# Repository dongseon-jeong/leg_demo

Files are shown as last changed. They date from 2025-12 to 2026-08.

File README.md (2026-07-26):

# 준비

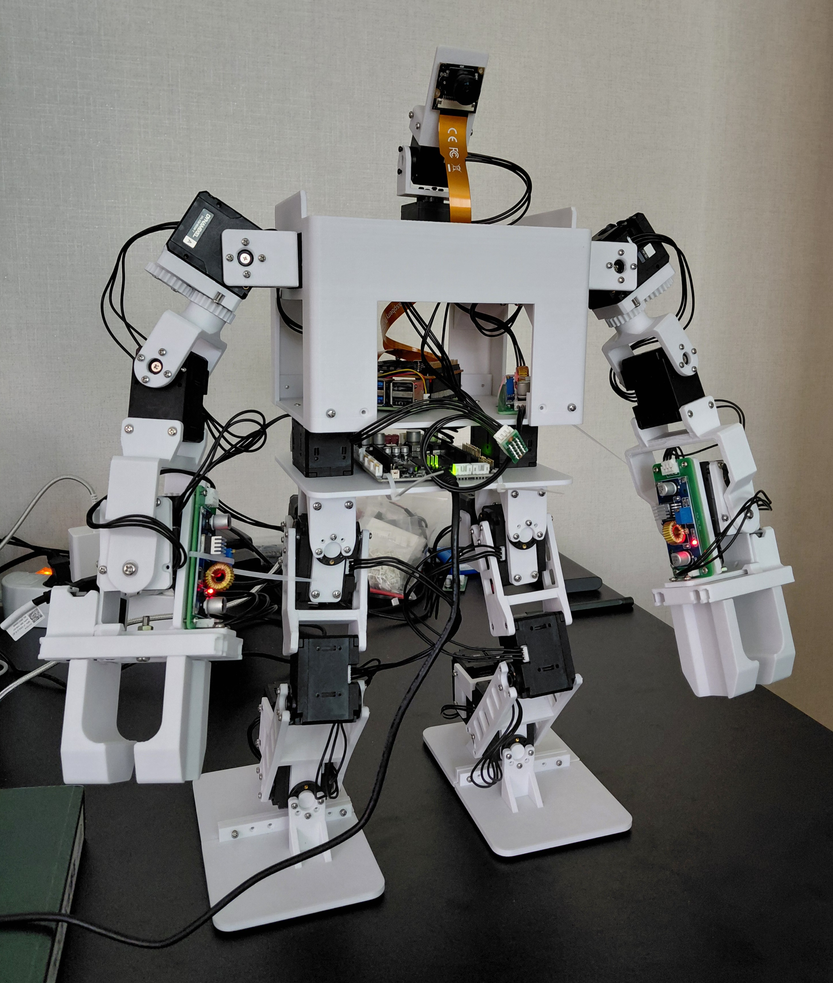
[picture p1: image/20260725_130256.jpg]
이미지

이미지

- 로봇
	- op3 leg + toddlerbot arm + rgb camera
- 최종로봇목표
	- 하체는 밸런싱 보드에서 균형 잡고 상체는 책상 위 주사위를 들어 번호 순으로 여러 개를 쌓는 작업을 구현 목표
- 학습
	- 하체는 isaaclab 강화학습
	- 상체는 lerobot 모방학습
	- +상하체 보강용 강화학습
- 추론
	- 상하체 모델 출력 + 보강용 모델 결과
- 부품
	- 하체 다이나믹셀 XL430-W350-R x 12
	- 상체 다이나믹셀 XL430 x 4 , 2XL430 x 4 , XL330 x 4
	- rgb 카메라
	- opencr, u2d2, rasberrypi5, ai hat+, buck converter, dynamixel hub
	- oculus quest2
	- 리튬베터리 11v
	- 나사 2 x 8, 2.5 x 8 많이 
	- 황동 히트 인서트 2 x 2, 2.5 x 2 많이
- system
  - edge inference : rasberrypi5(opencr) hailo8G debian venv ros noetic
  - simulation : rtx3080 desktop window11/ubuntu24.04 cuda12.8 isaacsim ros2 humble
  - train : ascent gx10 128G ubuntu cuda13
    - lerobot venv
    - isaaclab conda
  - teleop : rtx3080 desktop ubuntu24.04

이미지

# 4. 멀티 태스크 구현

# 5. 협동 로봇 구현

# 참고
https://github.com/ROBOTIS-GIT/ROBOTIS-OP3-Common  
https://www.robotis.com/service/downloadpage.php?ca_id=70  
https://emanual.robotis.com/docs/en/platform/op3/robotis_ros_packages/#robotis-ros-packages  
https://www.youtube.com/watch?v=tQziqSx-F80&t=1970s  
https://github.com/kscalelabs/ksim-gym/tree/master  
https://github.com/hshi74/toddlerbot

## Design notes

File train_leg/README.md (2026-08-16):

## 3d 프린팅 부품 설계

- 3d 프로그램
  - onshape : sas 서비스이고, isaacsim에서 바로 onshape로봇을 불러올 수 있음
  - fusion : autodesk cad나 maya 등이 익숙하다면 사용, claude 모델을 mcp로 연결해도 됨, 개인용도는 무료
- op3의 stl 파일이 있으나 본래 부분은 금속소재로 플라스틱 출력 시의 강도가 예상되지 않아, 새로 적당한 두께로 설계
- 모터 stl를 불러와서 사용하고 다른 부분의 스케치가 없어서 대략적으로 스케치하여 모델링 

[다이나믹셀 step파일](https://www.robotis.com/service/downloadpage.php?ca_id=70)  
나사, 각종 보드는 구글에서 모델링 파일 검색하면 쉽게 구할 수 있음

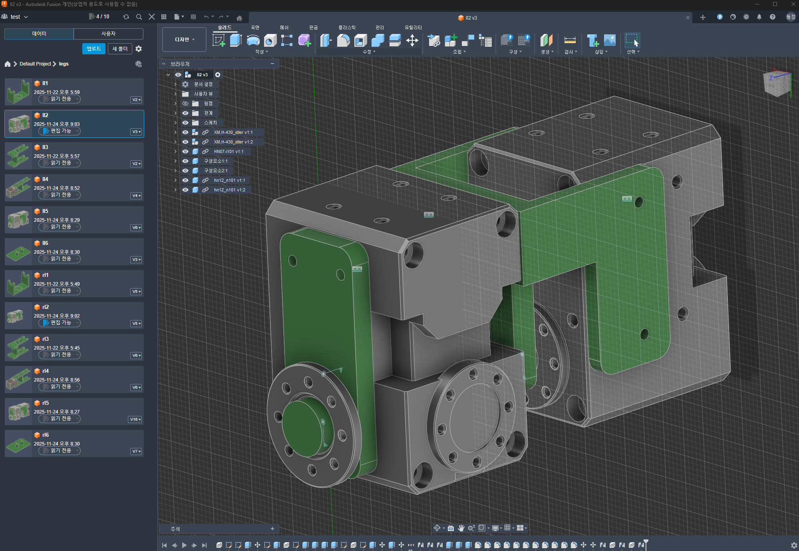
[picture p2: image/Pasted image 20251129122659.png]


## 3d 조립 완성 및 단순구조 변환

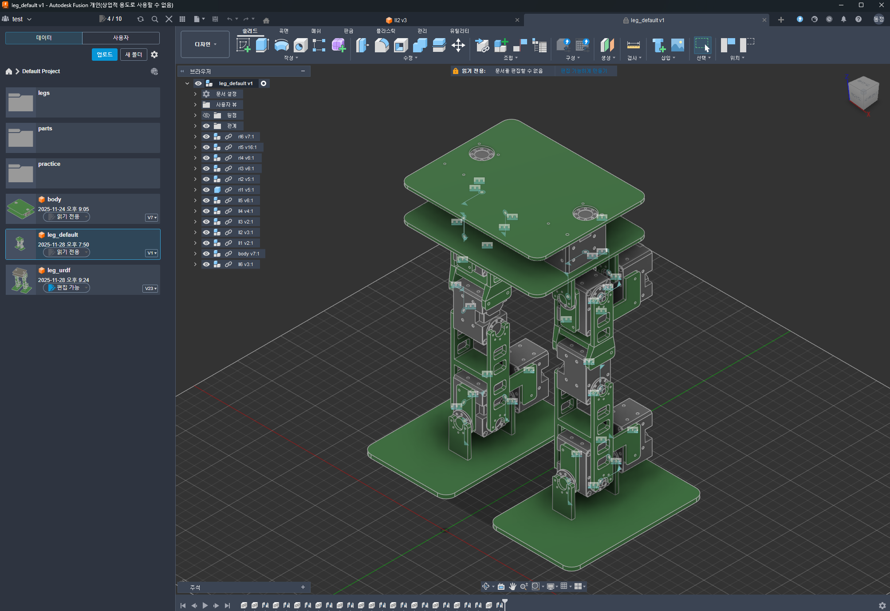
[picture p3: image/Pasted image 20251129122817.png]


- 하단 git 레포 참고하여 fusion 애드인 설치 진행
- 단순 구조로 변환
    - 모든 부위를 하나의 본체로만 구성
    - 모터 조인트 설정 시 부모 자식의 순서를 잘 맞춤, 조인트 한계각도 설정
	- 모터의 회전 조인트 및 구성요소 이름 설정  
	- fusion2urdf repo에 유의사항을 체크하여 아래와 같이 변환해야 urdf 변환 오류가 발생안됨

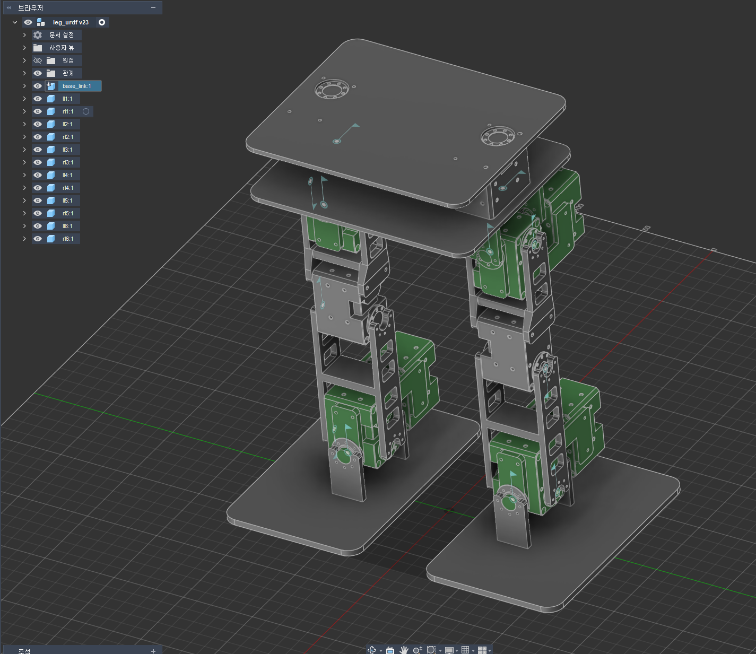
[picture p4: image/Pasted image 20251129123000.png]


https://github.com/dheena2k2/fusion2urdf-ros2
https://github.com/runtimerobotics/fusion360-urdf-ros2

## urdf 변환 및 usd 파일 생성

- urdf 추출 후 기본 세팅 진행  
추출경로 urdf폴더에 4개의 파일이 생성됨
*.gazebo *.trans *.xacro materials.xacro
xacro파일은 isaacsim에서 불어올 수 없어 urdf 변환이 필요함

- xacro > urdf 변환
  - ros2로 변환 가능
  - *.xacro의 확장자를 urdf로 바꾸고 내부에서 import하는 부분을 지운 뒤 .trans와 materials.xacro 파일 내부 내용을 urdf에 복사해도 됨
- 각종 오류 체크
  - inertia mass가 0이거나 damping 값이 없으면 isaacsim에서 오류 발생할 수 있어서 urdf에서 수정하거나 로드 후 값 입력
  - 각 joint drive의 stiffness는 isaacsim에서 입력

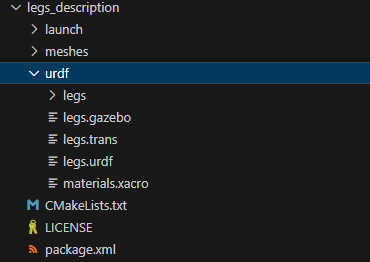
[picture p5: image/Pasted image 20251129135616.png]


- isaacsim & isaaclab 설치  
  - 환경 구성  
    - window 11 / rtx 3080 8G / 566.36 nvidia driver / cuda toolkit 12.8
    - anaconda 환경 python 3.11

        isaaclab 2.3.0  
        isaacsim 5.1.0  
        torch 2.7.0+cu128  
        torchvision 0.22.0+cu128  

- isaacsim 실행하여 urdf 파일 import하여
  - inertial collision friction damping stiffness 등 설정하여 usd 저장  
  - legs를 default prim 설정  
  - collider 등 기본 설정이 잘못되면 학습도 안됨  
  - root joint는 제거, 고정 암일 경우나 필요  

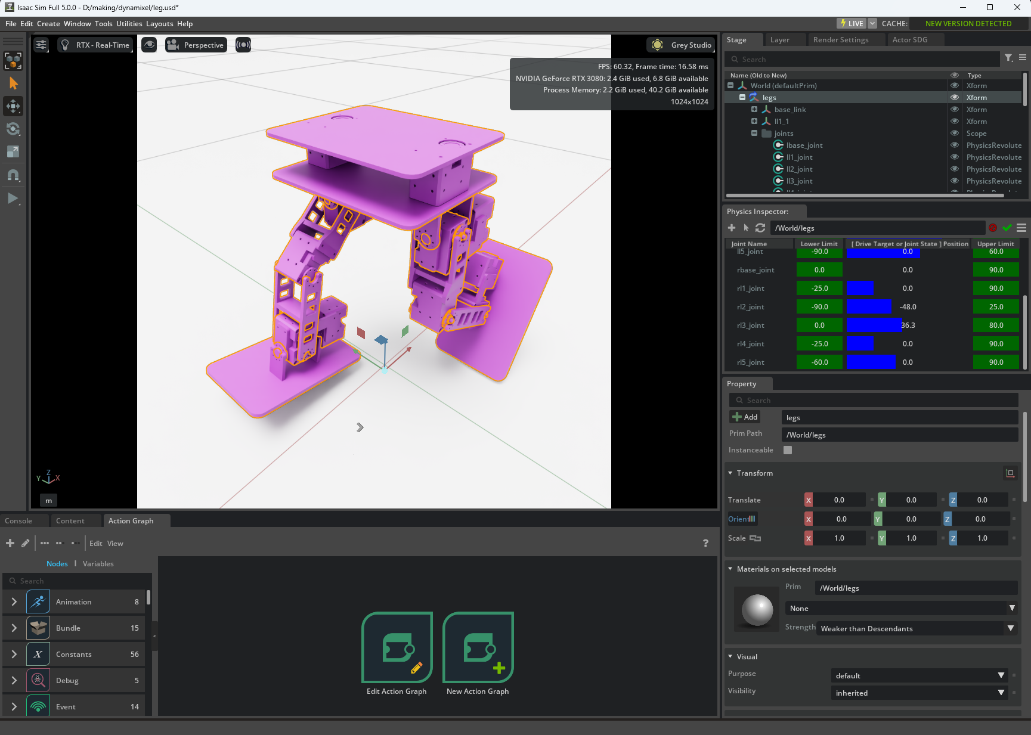
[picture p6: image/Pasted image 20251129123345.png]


## isaaclab 걷기 학습

환경 생성
```bash
./isaaclab.sh --new
Task type : Externel
Project path : d:/making/dynamixel/leg
Project name : leg
Direct | single-agent
rsl_rel, skrl
AMP, PPO
```

- 기본으로 생성하면 다음과 같이 생성됨
- cart pole로 되어 있어 커스텀 코드로 수정

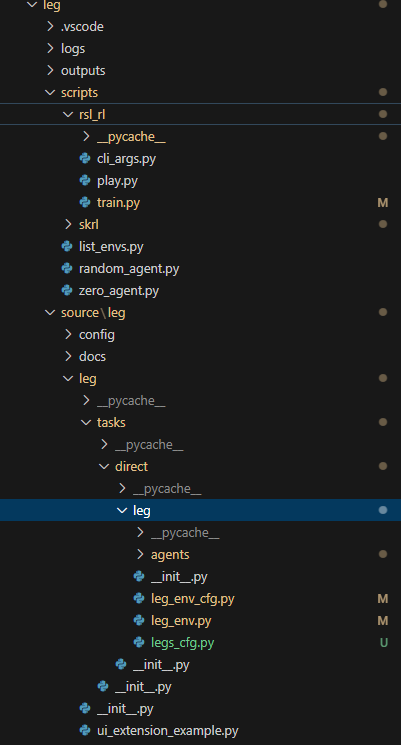
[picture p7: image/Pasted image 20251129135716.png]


- usd 파일  
leg\source\leg\leg\tasks\direct\leg\legs_cfg.py
```d
stiffness={".*": 5000.0}, # 너무 낮으면 몸의 무게감이 없음, 500이상 추천 
damping={".*": 10.0}, # 
velocity_limit_sim={".*": 10.0},
```

- 기본 환경 설정  
leg\source\leg\leg\tasks\direct\leg\leg_env_cfg.py

- 액션 스페이스 및 보상 등 중요한 환경 요소 수정  
leg\source\leg\leg\tasks\direct\leg\leg_env.py

**기본보상**  
해당 보상만으로 진행 시 한다리로 지탱하며 앞으로 콩콩 뛰어감  
```d
rew_alive # 안넘어지고 살아있으면 보상
rew_termination # 넘어지면 패널티
rew_upright # 바디의 높이가 유지되면 보상
rew_forward # 월드 x방향(로봇의 초기 앞쪽)으로 진행 시 보상, 너무 높으면 걷지 못하고 넘어짐
rew_vel_track # 원하는 속도에 도달하면 보상
rew_heading # 몸의 방향과 월드 x방향이 동일할 경우 보상, 없다면 진행 시 시계방향으로 돌아감
```
**추가보상1**  
걷기 모션을 위해 추가, 월드 x방향 직선 보행이 아닌 y방향이 포함된 대각선 보행이 발생
```d
rew_foot_spacing # 다리 간격, 없어도 무관할 듯
rew_foot_height # 발 높이, 발 교대 보상
rew_foot_flat # 발 평면 유지, 지면이 평평하다는 조건 하
```
**추가보상2**  
```d
rew_yaw_rate # 몸이 돌아가는 걸 방지, 게걸음으로 진행하는 걸 방지
rew_lateral_world # y방향 패널티, 게걸음으로 진행하는 걸 방지
```

- 모델 관련  
leg\source\leg\leg\tasks\direct\leg\agents\rsl_rl_ppo_cfg.py  

학습 초기 보상만을 얻기위한 요령을 터득하는 걸 방지하기 위해 탐색을 좀 더 하도록 수정
```d
    policy = RslRlPpoActorCriticCfg(
        init_noise_std=2.0, # 초기탐색
        actor_obs_normalization=False,
        critic_obs_normalization=False,
        actor_hidden_dims=[32, 32],
        critic_hidden_dims=[32, 32],
        activation="elu",
    )
    algorithm = RslRlPpoAlgorithmCfg(
        value_loss_coef=0.5, #
        use_clipped_value_loss=True,
        clip_param=0.2,
        entropy_coef=0.001, # 탐색 더하게
        num_learning_epochs=5,
        num_mini_batches=4,
        learning_rate=2.5e-4, #
        schedule="adaptive",
        gamma=0.99,
        lam=0.95,
        desired_kl=0.01,
        max_grad_norm=1.0,
    )
```

- 그 외 확인할 것  
leg\scripts\rsl_rl\train.py

- 학습 실행  
3080 pc 약 1시간 소요
```bash
# 환경 변수 추가
export BASE_PATH="복사한경로"

python scripts/rsl_rl/train.py --task=Template-Leg-Direct-v0 --num_envs=200 --max_iterations=5000
```

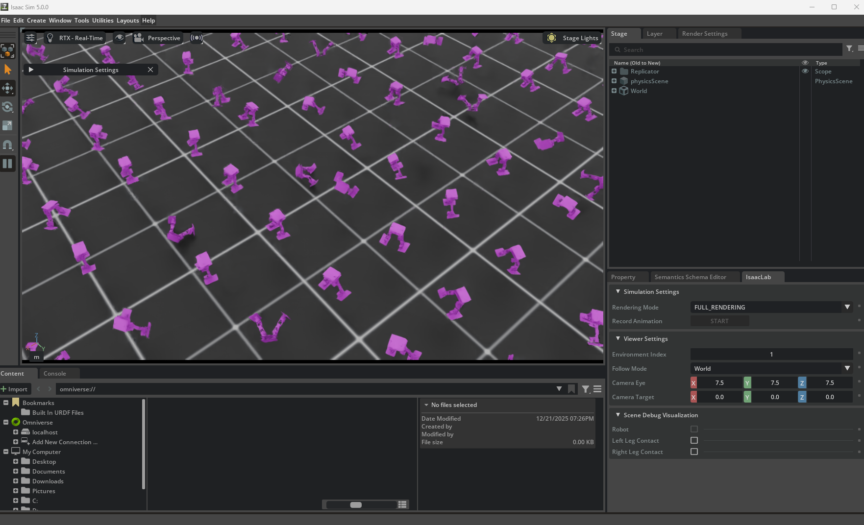
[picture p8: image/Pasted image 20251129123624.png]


모든 그래프가 우상향으로 그려지는지 모니터링
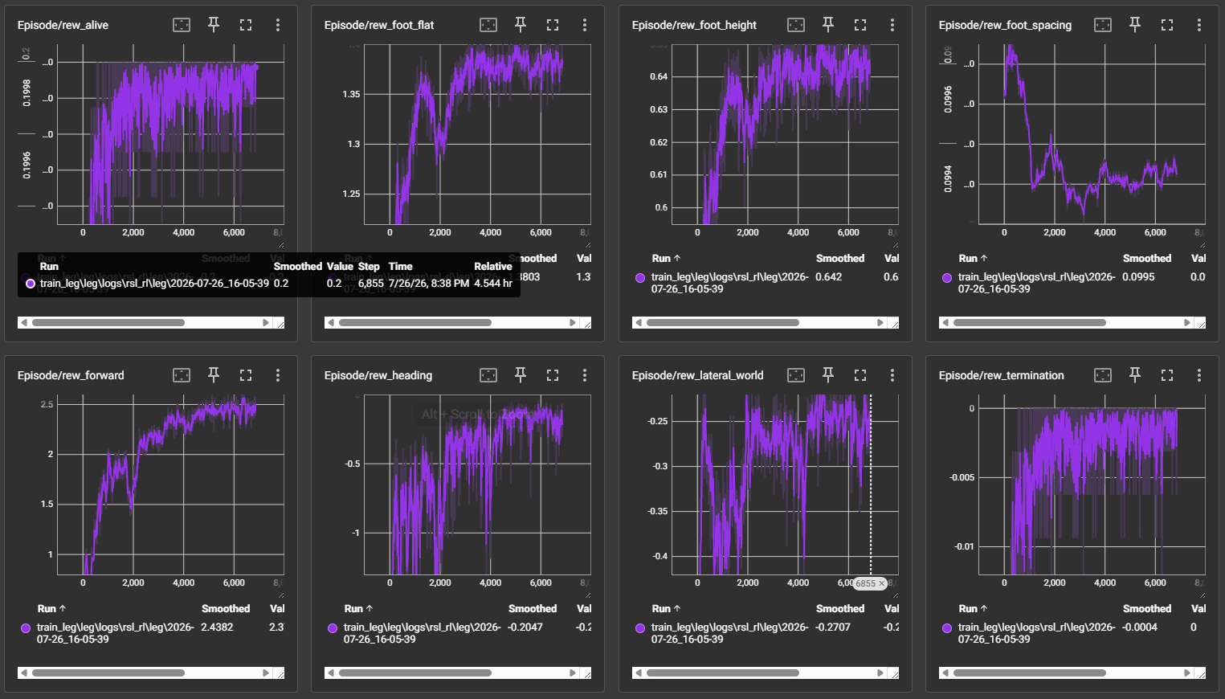
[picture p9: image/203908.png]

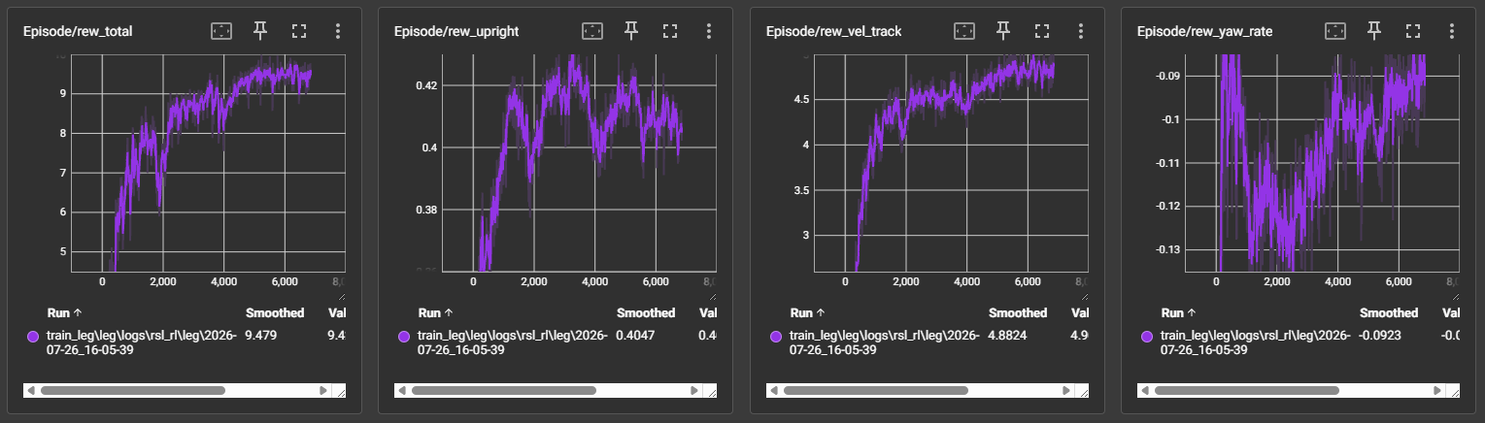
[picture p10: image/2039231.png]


```d
################################################################################
                     Learning iteration 6006/10000

                       Computation: 782 steps/s (collection: 1.874s, learning 0.171s)
             Mean action noise std: 1.59
          Mean value_function loss: 235.4259
               Mean surrogate loss: -0.0118
                 Mean entropy loss: 22.2170
                       Mean reward: 2657.49
               Mean episode length: 274.92
            Mean episode rew_alive: 0.2000
      Mean episode rew_termination: 0.0000
          Mean episode rew_upright: 0.4077
          Mean episode rew_forward: 2.5196
        Mean episode rew_vel_track: 4.9062
          Mean episode rew_heading: -0.1460
         Mean episode rew_yaw_rate: -0.0861
    Mean episode rew_lateral_world: -0.2155
     Mean episode rew_foot_spacing: 0.0995
      Mean episode rew_foot_height: 0.6573
        Mean episode rew_foot_flat: 1.4078
            Mean episode rew_total: 9.7506
--------------------------------------------------------------------------------
                   Total timesteps: 9611200
                    Iteration time: 2.04s
                      Time elapsed: 03:58:10
                               ETA: 02:38:21
```

- 추론
```bash
$env:BASE_PATH="{$project_path}/train_leg"
cd {$project_path}/train_leg/leg
python scripts/rsl_rl/play.py --task Template-Leg-Direct-v0 --num_envs 20 --checkpoint ./model_4999.pt
```

https://github.com/user-attachments/assets/a8d00207-1886-4957-bb30-7761e3211d93

## 3d 프린팅 조립
- 각 stl 파일 프린팅 > 구조 강도 개선과 조립 위해 특정 부품은 새롭게 모델링 진행  
프린팅 시 나사 구멍 등이 수축됨, 히트 인서트를 모든 나사 구멍에 삽입하는 것은 매우 힘든 일이므로 테스트 출력으로 나사 구멍 사이즈 조정 필요
- 각 부품 무게 측정 > 실제 무게로 usd 파일 설정

이미지

## 아두이노 opencr 모터컨트롤

**다이나밀셀 위저드로도 기본 설정 가능  
- 아두이노 ide에 opencr 설치 후 usb 연결하면 보드확인 및 라이브러리 사용 가능함  
- 처음 연결하면 공장 초기화 모터아이디는 모두 1번임, 모터 체인에 따라 차례대로 번호 세팅을 해야함  
  
여기에서는 왼발 위쪽 부터 차례대로 1~6번  
오른발 위쪽 부터 차례대로 7~12번 세팅  

```arduino
check_motor_id.io 보드를 usb 연결 후 코드 실행 하면 시리얼 모니터로 모터 아이디 번호 확인 가능
edit_motor_id.io 실행 하면 모터 아이디를 수정 가능
check_motor_position.io 현 모터의 포지션 수치를 시리얼 모니터로 확인
```

**중요
urdf에 저장된 조인트 라디안 min max값을 적용하면 실제 모터 방향과 다르게 움직여 다음과 같이 적용함 (fusion에서 접합 구동으로 로봇을 조정 후 urdf 파일로 변환한 이유일 것으로 추측)  

```arduino
const float URDF_MIN_RAD[12] = {
  -1.57,   -1.57,   -1.57,    0.0,   -0.43, -1.04, // 왼발 (1번: -1.57)
  0.0,     -0.43,   -0.43,   -1.39,  -1.57, -1.57  // 오른발 (7번: 0.0)
};

const float URDF_MAX_RAD[12] = {
  0.0,    0.43,     0.43,     1.39,   1.57,  1.57,  // 왼발 (1번: 0.0)
  1.57,   1.57,     1.57,     0.0,    0.43,  1.04   // 오른발 (7번: 1.57)
};
```

다음값을 각 모터에 입력하면 라디안 변환하여 움직여짐(180도에 해당하는 모터 값은 2048임, 1000은 약 90도)  
```arduino
1: -1000 ~ 0
2: -1000 ~ +200
3: +1000 ~ -200
4: -1000 ~ 0
5: -1000 ~ +200
6: -1000 ~ +300

7: 0 ~ +1000
8: -200 ~ +1000
9: -1000 ~ +200
10: 0 ~ +1000
11: -200 ~ +1000
12: -300 ~ +1000
```

```arduino
motor_control.io opencr 구동 시 위치를 초기값으로 설정하게끔 되어 있음, 라즈베리파이에서 값을 python 스크립트나 ros로 통신하기 위한 코드, usb 연결하여 실행 후 업로드 완료하면 라즈베리파이에 usb연결하여 사용
```

## rasberrypi opencr 연결
- opencr과 rasberrypi는 usb로 연결
- rasberrypi 환경설정
  - 데비안 설치
  - venv Python 3.13.5
  - ros noetic container
    - ros:noetic-ros-base-focal  
- 라즈베리파이 파이썬 스크립트 컨트롤  
venv에서 rpi_joint_teleop.py 실행 후 원하는 모터와 라디안(90도 = 1024) 입력

- ros 컨트롤 (rbiz에서 슬라이더로 모터를 컨트롤)
라즈베리파이는 ros noetic 컨테이너 실행

```bash
# 초기 세팅 외부 호스트
# 1. 모든 로컬 사용자의 디스플레이 접근 제한을 완전히 해제 (보안 비활성화) 
xhost + 
# 2. Xauthority 인증 파일 권한을 모두가 읽을 수 있도록 개방 
chmod 644 ~/.Xauthority

# 초기 세팅 컨테이너 내부
apt update
apt install -y ros-noetic-joint-state-publisher-gui ros-noetic-robot-state-publisher ros-noetic-rviz
apt install -y python-is-python3
apt install -y python3-pip 
pip3 install pyserial

# 컨테이너 외부 호스트
# 1. 디스플레이 :0 환경변수를 임시 지정하여 xhost 무력화
DISPLAY=:0 xhost +local:docker

# 2. 만약 위 명령어가 실패하면 디바이스 전체 개방으로 재시도
DISPLAY=:0 xhost +

# 컨테이너 내부
source /opt/ros/noetic/setup.bash

cd /workspace/catkin_ws 
# catkin_make 
source devel/setup.bash # 런치 파일 실행 

# 1. 완벽한 소프트웨어 렌더링 강제 (Mesa softpipe 지정) 
export LIBGL_ALWAYS_SOFTWARE=1 
export GALLIUM_DRIVER=softpipe 
# 2. X11 공유 메모리 버퍼 완전히 비활성화 (Segmentation Fault 차단 핵심) 
export QT_X11_NO_MITSHM=1 
export MITSHM=0 
# 3. 만약 하이딩된 세션 에러 방지를 위해 디스플레이 다시 선언 
export DISPLAY=:0
roslaunch opencr_rcm_control display_and_control.launch
```

## isaacsim sim2real 구현

conda에 isaacsim은 ros2라서 ros1과 통신할 브릿지 역할의 웹소켓을 같이 띄움  
isaacsim에서 조인트 damping stiffness 설정 필요

```
[호스트 isaac_bin conda]
  Isaac Sim 5.0
  → ROS2 /joint_states 퍼블리시
  → roslibpy 클라이언트
        ↕ WebSocket (LAN)
[라즈베리파이 Docker: ros_noetic]
  rosbridge_server (WebSocket :9090)
  → roscore
  → 로봇 (/dev/ttyACM0)
```

ros1 rasberrypi 컨테이너
```bash
apt update 
apt install -y ros-noetic-rosbridge-suite 
source /opt/ros/noetic/setup.bash 
roslaunch rosbridge_server rosbridge_websocket.launch
```

conda
```bash
pip install roslibpy

isaacsim --enable isaacsim.ros2.bridge --enable isaacsim.ros2.sim_control --enable omni.isaac.ros2_bridge
```

leg_w.usd 파일 로드
플레이 후 scripts editor 실행
```bash
#!/usr/bin/env python3
import rospy
from sensor_msgs.msg import JointState
import serial
import math

RAD_TO_DXL_STEP = 2048.0 / math.pi

class ROSSerialBridgeFast:
    def __init__(self):
        rospy.init_node('ros_serial_bridge', anonymous=False)
        
        # 1. 초고속 통신을 위해 1Mbps로 보레이트 상향 (OpenCR 소스도 맞춰야 함)
        self.port = "/dev/ttyACM0"
        self.baud = 115200  
        
        try:
            # write_timeout을 추가하여 시리얼 전송 지연이 메인 루프를 막는 현상 방지
            self.py_serial = serial.Serial(port=self.port, baudrate=self.baud, timeout=0.001, write_timeout=0.001)
            rospy.loginfo("➔ [FAST] Connected to OpenCR at 1Mbps!")
        except Exception as e:
            rospy.logerr(f"➔ Failed to connect OpenCR: {e}")
            return

        self.last_sent_steps = [0] * 12

        self.joint_id_map = {
            "lbase_joint": 1, "ll1_joint": 2, "ll2_joint": 3, "ll3_joint": 4, "ll4_joint": 5, "ll5_joint": 6,
            "rbase_joint": 7, "rl1_joint": 8, "rl2_joint": 9, "rl3_joint": 10, "rl4_joint": 11, "rl5_joint": 12
        }

        # 2. tcp_nodelay=True를 추가하여 ROS 네트워크 패킷 지연(Nagle 알고리즘)을 원천 차단
        rospy.Subscriber("/joint_states", JointState, self.joint_state_callback, queue_size=1, tcp_nodelay=True)
        rospy.loginfo("➔ [FAST] ROS-Isaac Serial Bridge Running...")

    def joint_state_callback(self, msg):
        cmd_tokens = []
        any_changed = False

        for i, name in enumerate(msg.name):
            if name in self.joint_id_map:
                joint_id = self.joint_id_map[name]
                radian = msg.position[i]
                
                if joint_id == 1:
                    radian = -radian
                
                step_offset = int(radian * RAD_TO_DXL_STEP)

                # 3. 필터 컷오프를 5스텝(약 0.4도)으로 상향하여 무의미한 고주파 트래픽 차단
                if abs(step_offset - self.last_sent_steps[joint_id - 1]) > 10:
                    cmd_tokens.append(f"{joint_id},{step_offset}")
                    self.last_sent_steps[joint_id - 1] = step_offset
                    any_changed = True

        if any_changed and cmd_tokens:
            serial_cmd = "/".join(cmd_tokens) + "\n"
            try:
                self.py_serial.write(serial_cmd.encode())
                # 속도 최적화를 위해 실시간 주크박스 로그(rospy.loginfo)는 주석 처리합니다.
                # 터미널에 프린트를 찍는 행위 자체가 파이썬 연산 속도를 엄청나게 갉아먹습니다.
            except serial.SerialTimeoutException:
                pass # 시리얼 버퍼 밀림 발생 시 과감히 패킷 드랍하여 실시간성 유지

    def shutdown_hook(self):
        if hasattr(self, 'py_serial') and self.py_serial.is_open:
            self.py_serial.close()

if __name__ == '__main__':
    bridge = ROSSerialBridgeFast()
    rospy.on_shutdown(bridge.shutdown_hook)
    rospy.spin()
```

라즈베리파이에서 로스 실행 후 rostopic echo /joint_states 로 조인트 확인 가능

브릿지 실행

```bash
cd /workspace/catkin_ws 
source devel/setup.bash 
chmod +x src/opencr_rcm_control/scripts/ros_serial_bridge.py # 파이썬 중계 노드 단독 기동! 

rosrun opencr_rcm_control ros_serial_bridge.py
```

## locomotion 구현

zmp  
지면과 발바닥 사이에 마찰력이 없어서 발바닥에 미끄럼 방지 고무 부착 필요  
venv에서 zmp_walk.py 실행  
https://github.com/user-attachments/assets/5ca6f1dd-a935-40f1-bca3-d703732ec3d1

[참고](https://ieeexplore.ieee.org/document/4209488)

강화학습모델 realworld 적용  
학습 config파일의 엑추에이터 순서와 실제 low level 컨트롤하는 모터 순서 매칭 필요  
```
    actuators={
        "legs_dxl": ImplicitActuatorCfg(
            joint_names_expr=[
                "lbase_joint",
                "rbase_joint",
                "ll1_joint",
                "rl1_joint",
                "ll2_joint",
                "rl2_joint",
                "ll3_joint",
                "rl3_joint",
                "ll4_joint",
                "rl4_joint",
                "ll5_joint",
                "rl5_joint",
            ],
            stiffness={".*": 5000.0}, # 500.0
            damping={".*": 10.0},
            velocity_limit_sim={".*": 10.0},
        ),
    }
```

navigation  
라이다 없이 nav2 가능한지 확인?

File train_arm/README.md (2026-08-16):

## 3d 프린팅 부품 설계

- 팔 설계 변경  
오리지날  
이미지
변경(덕컨버터 마운트 적용, 엘보 자유도 -1)  
이미지

- 모터 볼트 컨버터용 pcb 제작  
easyEDA 사용
이미지
이미지

## 3d 프린팅 조립
- 배선 정리  
  - 양팔 전압 변경
    - 2xl430(11.1v) > xl430(11.1v) > 2xl430(11.1v) > buck converter > xl330(5v) 
  - 양다리
    - xl430(11.1v) > xl430(11.1v) > xl430(11.1v) > xl430(11.1v) > xl430(11.1v) > xl430(11.1v)
  - 헤드 전압 변경
    - duck converter > xl330(5v) > xl330(5v) 
  - opencr ttl 소켓 3개 로봇양팔,다리,머리로 5개 케이블로 허브를 중간에 둬야함
  
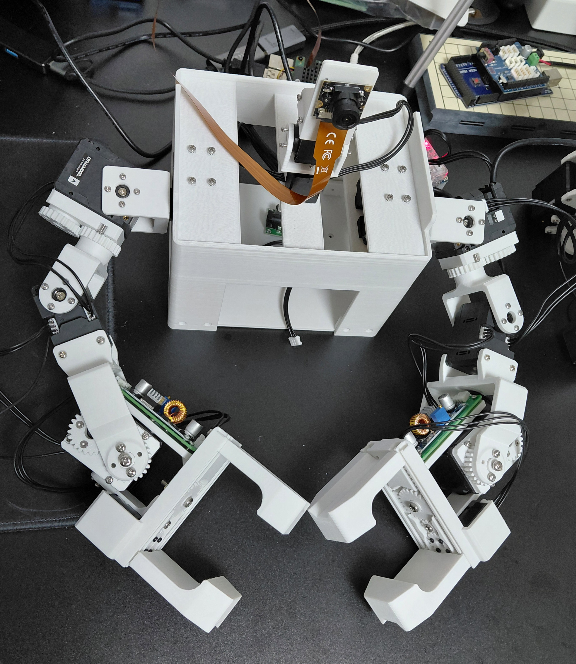
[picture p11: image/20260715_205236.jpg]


## isaacsim sim2real 구현
- urdf 추출  
이미지

urdf 에서 기어비를 별도 나타내지 않고, low level 컨트롤 코드에서 반대방향으로 동작하도록 코딩  

그립퍼의 핑거 부분은 그리퍼 드라이븐 원 기어가 돌아가면 각 핑거의 톱니가 같이 움직이는 슬라이드 기어로 퓨전에서는 링크로 연결할 수 있으나 urdf에서는 다음과 같이 작성  
이미지
```xml
<joint name="lgripper_joint" type="revolute">
  <origin xyz="0.019 0.0397 0.0" rpy="0 0 0"/>
  <parent link="lgripper_1"/>
  <child link="lgrip_gear_1"/>
  <axis xyz="-0.0 1.0 0.0"/>
  <dynamics damping="10.0" friction="0.0"/>  <!-- 이 줄 추가 -->
  <limit upper="0.8727" lower="-5.2360" effort="100" velocity="100"/>
</joint>

<!-- 슬레이브 1: fin1 -->
<joint name="lgrip_fin1_slider" type="prismatic">
  <origin xyz="0.018907 0.0389 0.0192" rpy="0 0 0"/>
  <parent link="lgripper_1"/>
  <child link="lgrip_fin1_1"/>
  <axis xyz="1.0 0.0 0.0"/>
  <dynamics damping="10.0" friction="0.0"/>
  <limit upper="0.007" lower="-0.02" effort="100" velocity="100"/>
  <mimic joint="lgripper_joint" multiplier="0.00869" offset="0.0"/>
</joint>

<!-- 슬레이브 2: fin2 (반대 방향) -->
<joint name="lgrip_fin2_slider" type="prismatic">
  <origin xyz="0.019 0.0389 -0.0192" rpy="0 0 0"/>
  <parent link="lgripper_1"/>
  <child link="lgrip_fin2_1"/>
  <axis xyz="1.0 0.0 0.0"/>
  <dynamics damping="10.0" friction="0.0"/>
  <limit upper="0.02" lower="-0.007" effort="100" velocity="100"/>
  <mimic joint="lgrip_fin1_slider" multiplier="-1.0" offset="0.0"/>
</joint>
```

isaacsim import하여 damping, stifness 등 점검  
카메라 세팅 등 하여 usd 파일로 저장
이미지

moveit
```bash
wsl -d Ubuntu-20.04
sudo apt update
sudo apt install -y ros-noetic-moveit ros-noetic-moveit-visual-tools
sudo apt install python3-empy

source /opt/ros/noetic/setup.bash
cd /mnt/d/making/dynamixel/rasberrypi/catkin_ws
# catkin_make # conda deactivate

source devel/setup.bash
# MoveIt 로드

OGRE_RTT_MODE=Copy \
LIBGL_ALWAYS_SOFTWARE=1 \
GALLIUM_DRIVER=llvmpipe \
QT_X11_NO_MITSHM=1 \
roslaunch moveit_setup_assistant setup_assistant.launch
```
이미지  
무브잇으로 엔드이펙터를 움직여 플랜 생성  

curobo or cumotion  

## 오큘러스 teleoperation  
- isaac teleop  
  - vr헤드셋에 별도 설치 없이 web 브라우저로 서버 접속하여 데이터 전송  
  - 현시점 ubuntu 환경에서만 가능  
  - 아직 윈도우 미지원으로 멀티부팅 우분투 24.04 설치 후 진행  

- isaacsim/lab 가상환경 생성 후 isaacsim 실행(vr을 위한 xr로 진행)
```
source env_isaaclab/bin/activate
source /home/dongseon/.cloudxr/run/cloudxr.env
export ROS_DISTRO=jazzy
export RMW_IMPLEMENTATION=rmw_fastrtps_cpp
export ROS_DOMAIN_ID=0
export ROS_LOCALHOST_ONLY=1

export LD_LIBRARY_PATH=$LD_LIBRARY_PATH:/home/dongseon/env_isaaclab/lib/python3.11/site-packages/isaacsim/exts/isaacsim.ros2.bridge/jazzy/lib

isaacsim \
  /home/dongseon/env_isaaclab/lib/python3.11/site-packages/isaacsim/apps/isaacsim.exp.base.xr.vr.kit --enable isaacsim.ros2.bridge --enable omni.graph.window.action --enable omni.graph.ui --enable omni.kit.window.script_editor
```
- isaacsim 실행 후 arm.usd파일을 열어 플레이 실행  
액션그래프
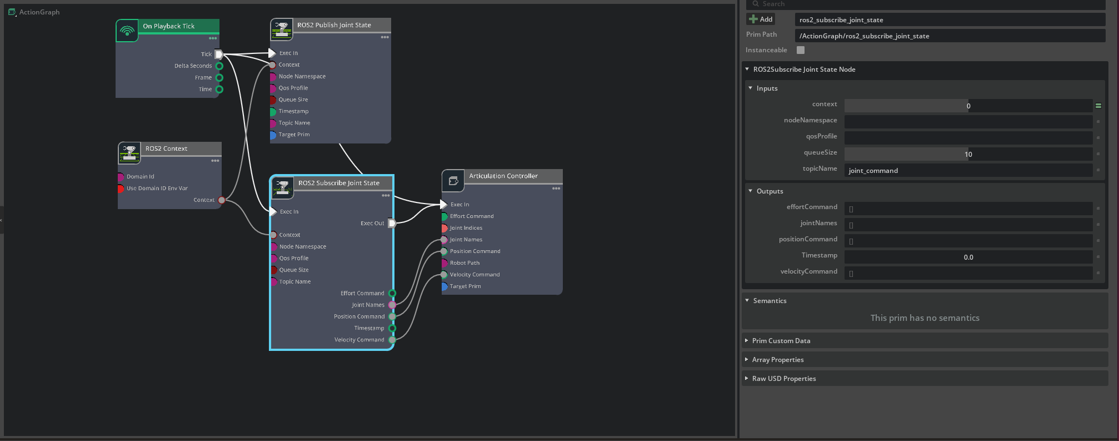
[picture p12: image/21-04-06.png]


isaacteleop 가상환경 생성
```
cd ~/IsaacTeleop
source .venv/bin/activate

source /opt/ros/jazzy/setup.bash

export ROS_DISTRO=jazzy
export RMW_IMPLEMENTATION=rmw_fastrtps_cpp
export ROS_DOMAIN_ID=0
export ROS_LOCALHOST_ONLY=1

python examples/teleop_ros2/python/teleop_ros2_node.py \
  --ros-args \
  -p mode:=controller_teleop \
  -p rate_hz:=30.0 \
  -p world_frame:=world \
  -p accept_eula:=true
```
기존 isaacteleop ros 스크립트를 실행한 뒤 메뉴얼과 같이 vr헤드셋 브라우저에서 웹서버를 접속 후 connect  
[메뉴얼참고](https://nvidia.github.io/IsaacTeleop/main/getting_started/quick_start.html)  
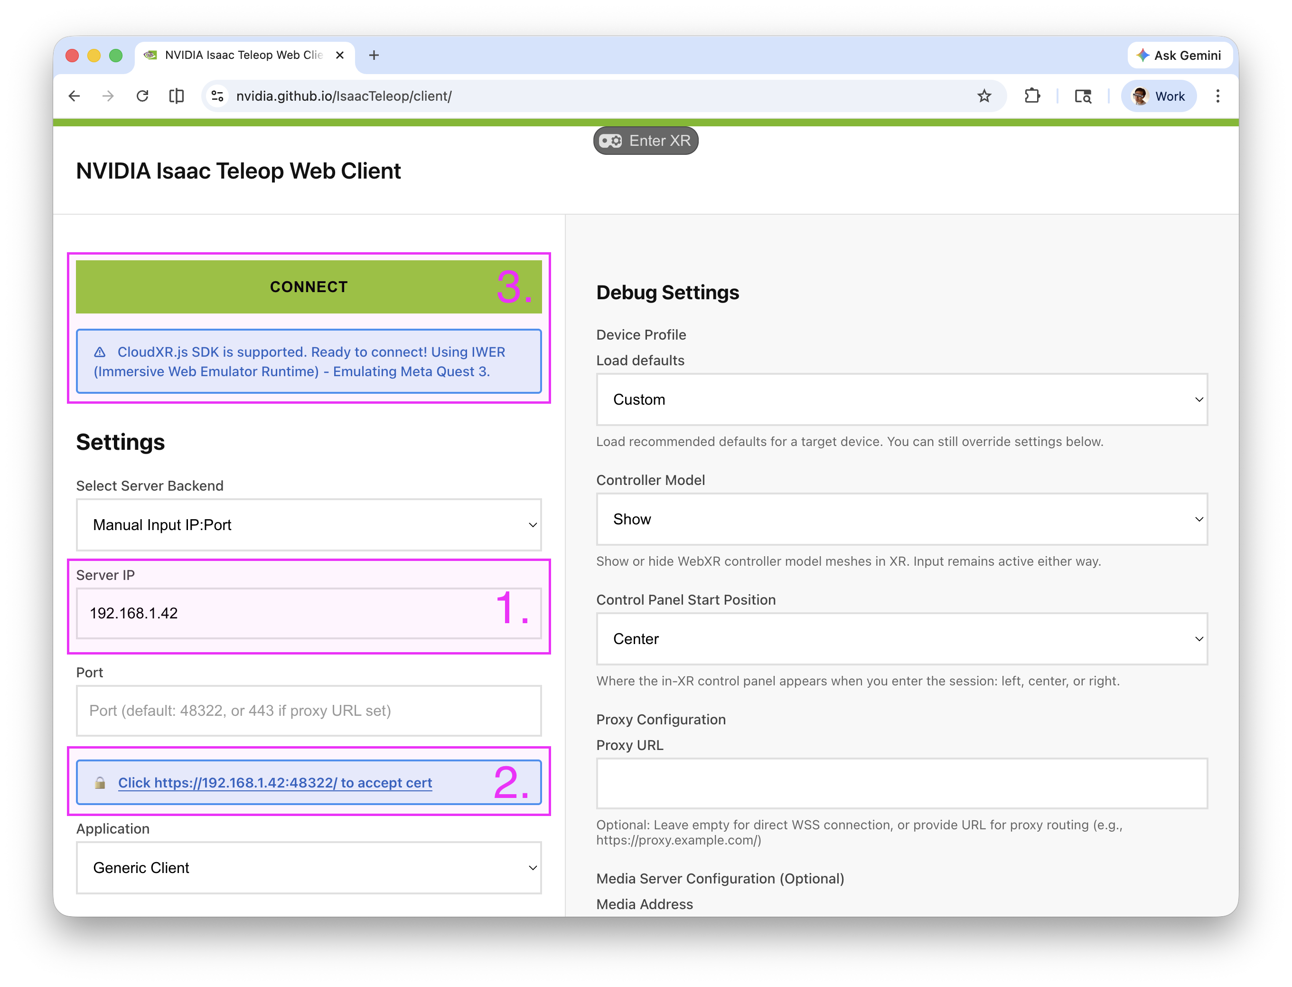
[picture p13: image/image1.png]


isaacsim과 teleop서버를 실행 후 토픽리스트를 확인  
```
source /opt/ros/jazzy/setup.bash

export ROS_DISTRO=jazzy
export RMW_IMPLEMENTATION=rmw_fastrtps_cpp
export ROS_DOMAIN_ID=0
export ROS_LOCALHOST_ONLY=1

ros2 node list
ros2 topic list
```

isaacsim 스트립트 에디터에서 스크립트를 실행 후 컨트롤러를 움직이면 로봇의 엔드이펙터가 따라움직이는 걸 확인  

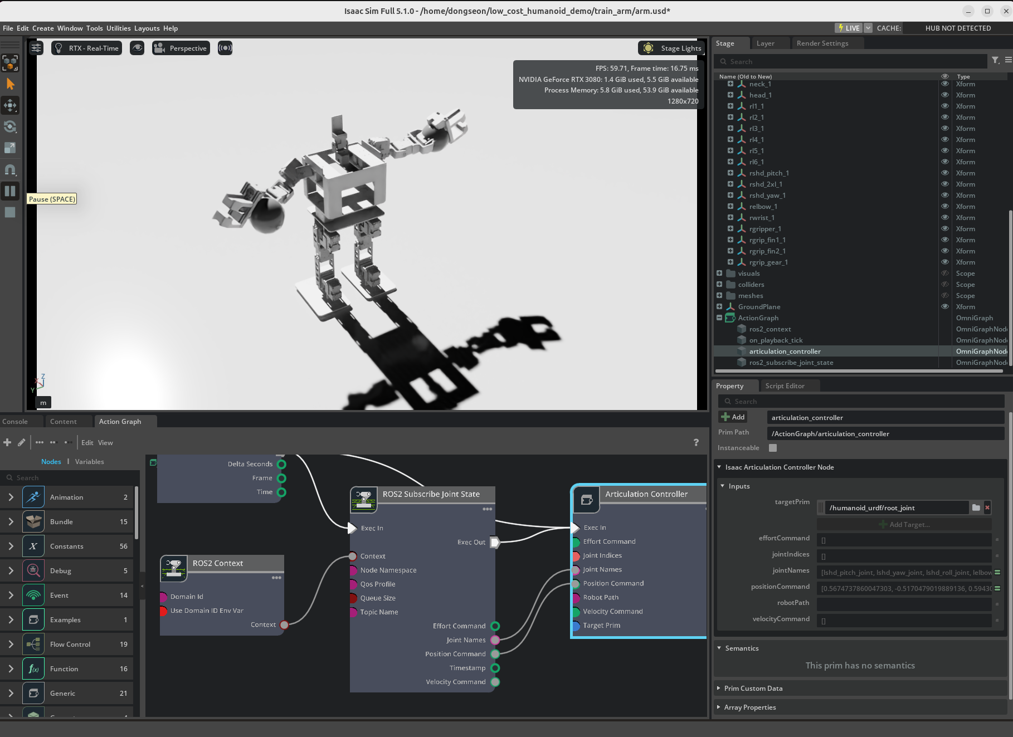
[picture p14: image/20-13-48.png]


- lerobot dataset 변환

## 합성 데이터 셋 생성
- isaacsim augmentation + 3d gaussian splatting  
- cosmos transfer + inverse dynamics model 활용  

## vla manipulation 학습
- lerobot 학습

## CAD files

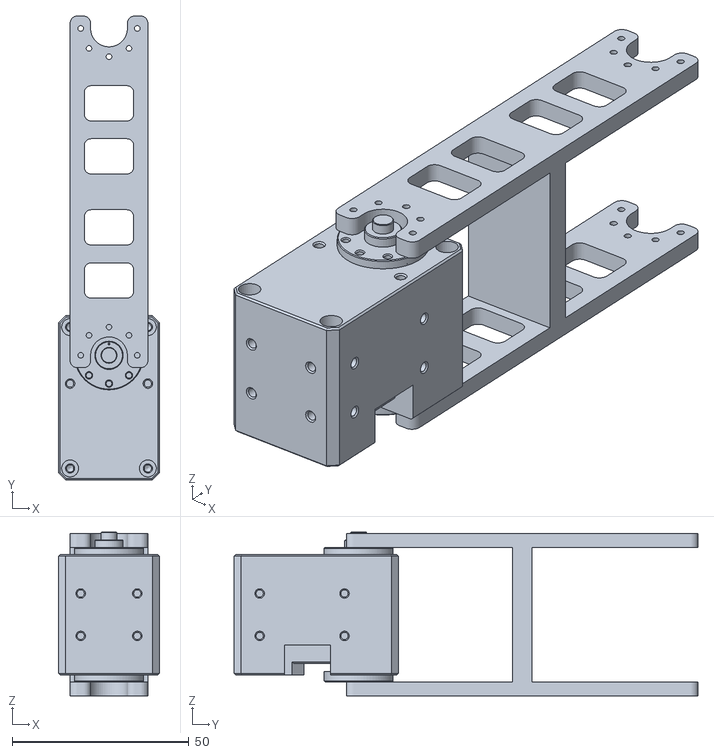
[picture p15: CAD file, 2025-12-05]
3d/ll4.stl
28.5 x 131.2 x 46.4

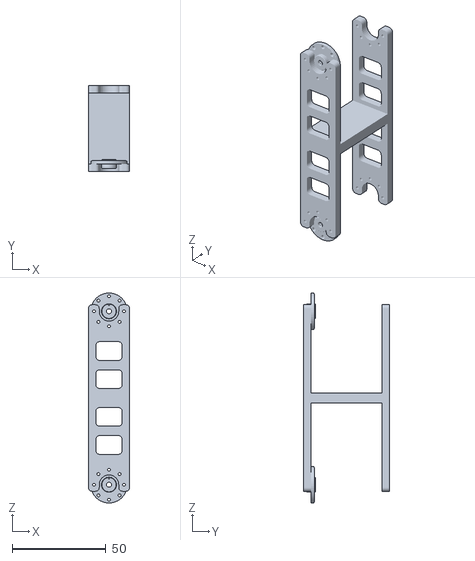
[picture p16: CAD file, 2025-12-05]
legs_description/meshes/ll4_1.stl
22.0 x 46.0 x 112.0

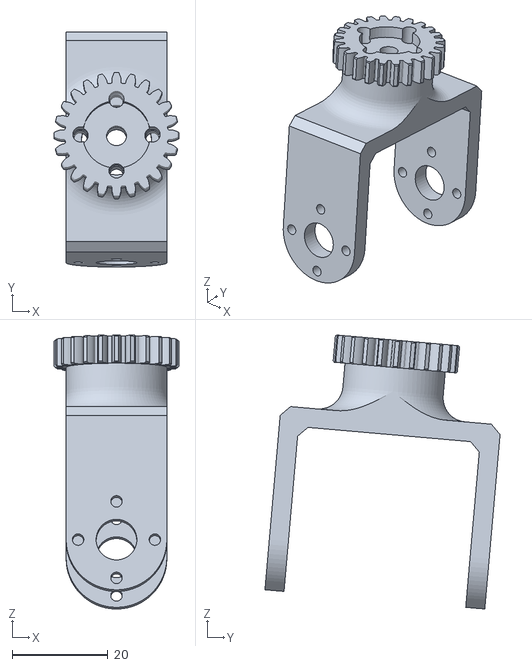
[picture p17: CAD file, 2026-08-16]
train_arm/humanoid_urdf_description/meshes/rshd_yaw_1.stl
26.0 x 49.0 x 57.1

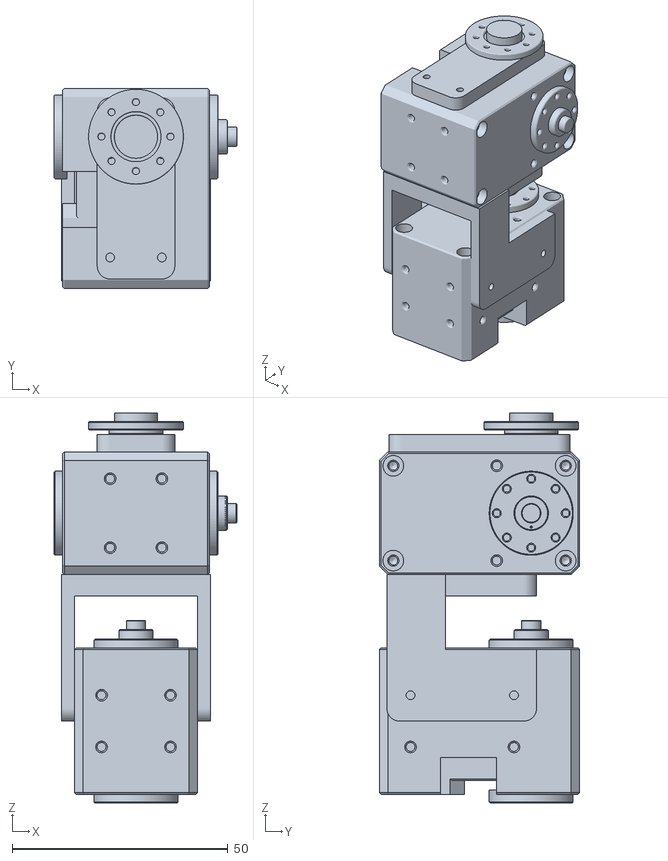
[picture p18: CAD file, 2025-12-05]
3d/rl5.stl
42.4 x 46.5 x 90.5

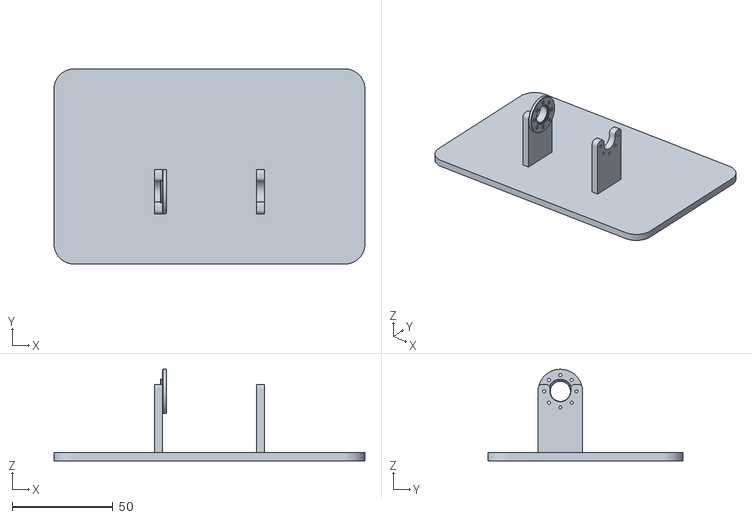
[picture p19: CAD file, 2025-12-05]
legs_description/meshes/rl6_1.stl
154.5 x 97.0 x 45.5

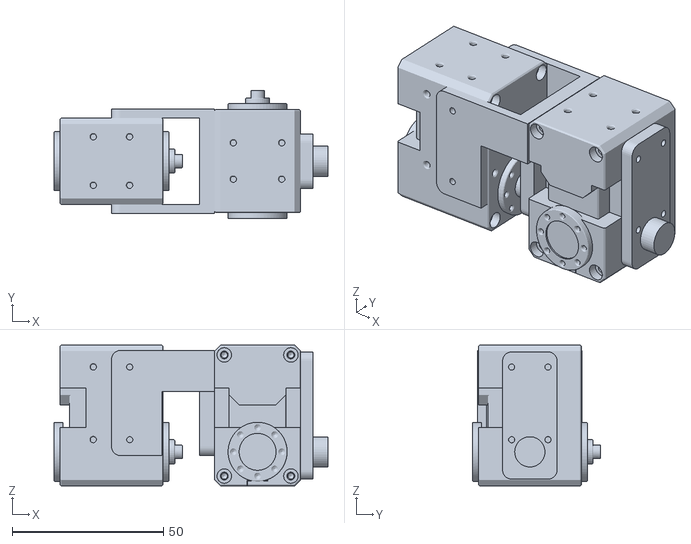
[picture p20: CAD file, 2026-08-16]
train_arm/humanoid_urdf_description/meshes/ll5_1.stl
90.5 x 42.4 x 46.5

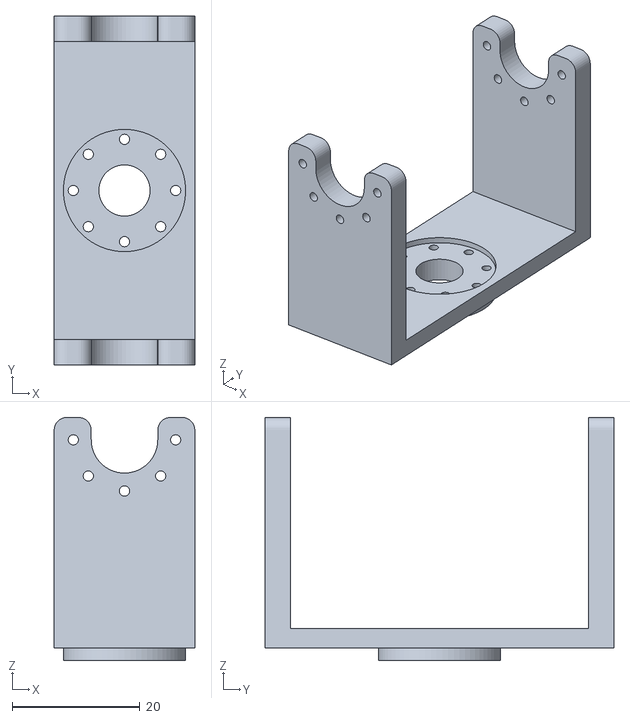
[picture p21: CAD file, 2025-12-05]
3d/rl1.stl
22.0 x 54.5 x 38.0

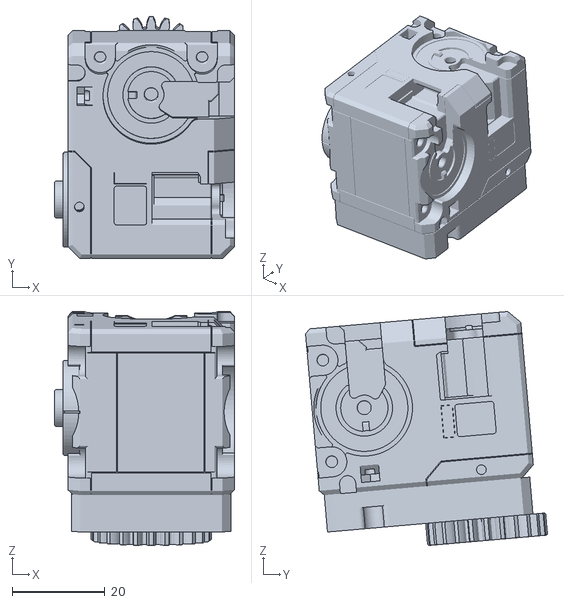
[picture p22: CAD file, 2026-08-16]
train_arm/humanoid_urdf_description/meshes/lshd_2xl_1.stl
38.9 x 52.2 x 50.5

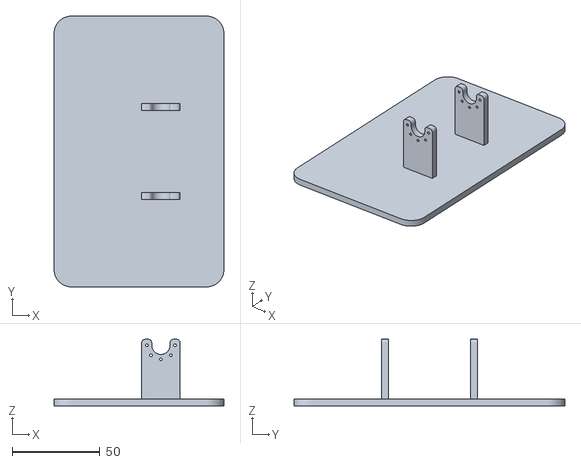
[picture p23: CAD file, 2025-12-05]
3d/ll6.stl
97.0 x 154.5 x 38.0

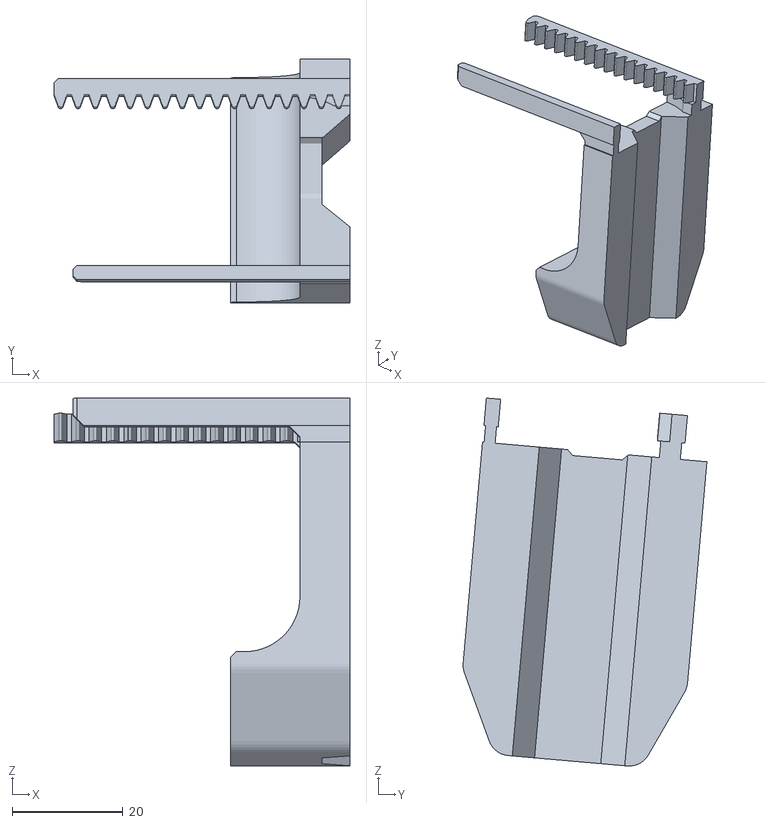
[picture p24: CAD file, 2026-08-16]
train_arm/humanoid_urdf_description/meshes/rgrip_fin2_1.stl
53.4 x 44.0 x 66.5

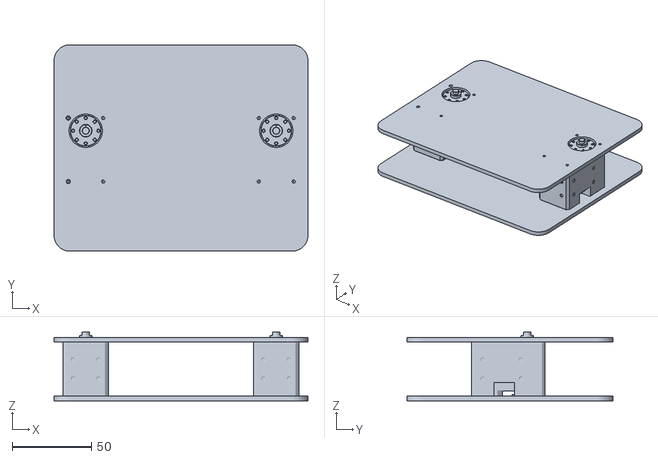
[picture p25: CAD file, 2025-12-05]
3d/body.stl
160.0 x 130.0 x 43.4

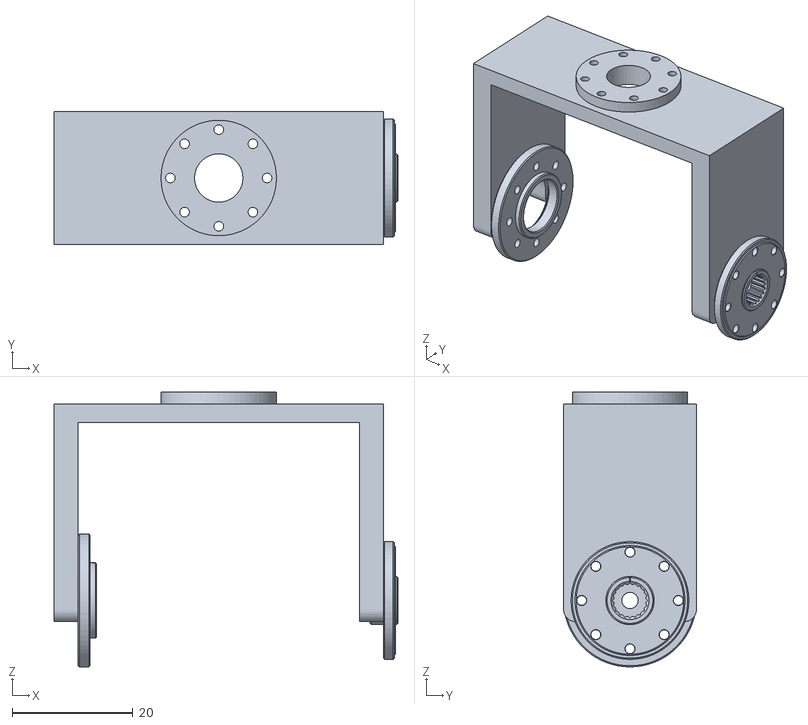
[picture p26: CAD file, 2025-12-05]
legs_description/meshes/rl1_1.stl
56.9 x 22.0 x 45.5

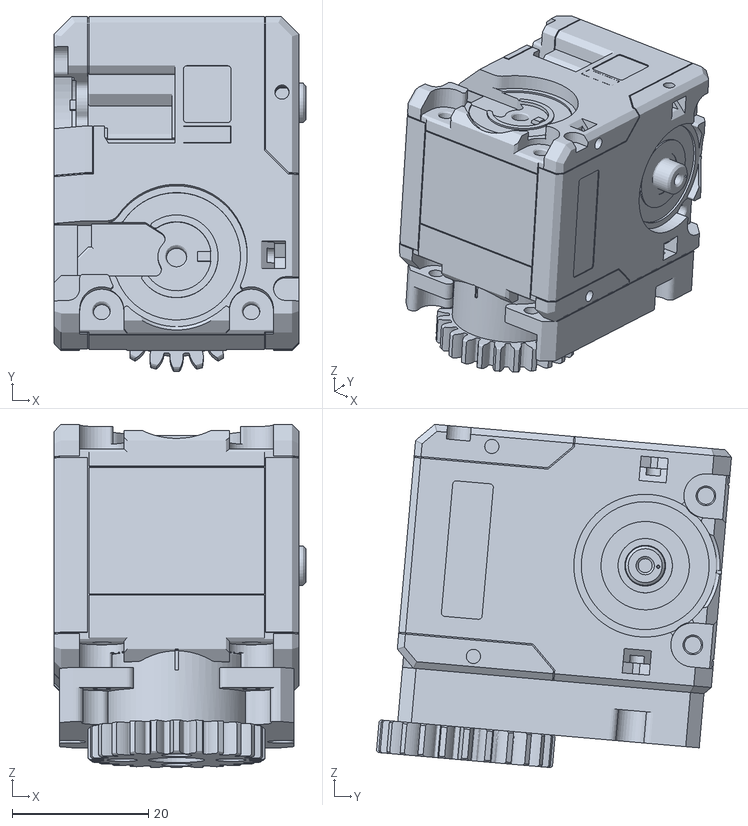
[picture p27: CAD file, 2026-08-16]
train_arm/humanoid_urdf_description/meshes/rshd_2xl_1.stl
37.0 x 52.2 x 50.5

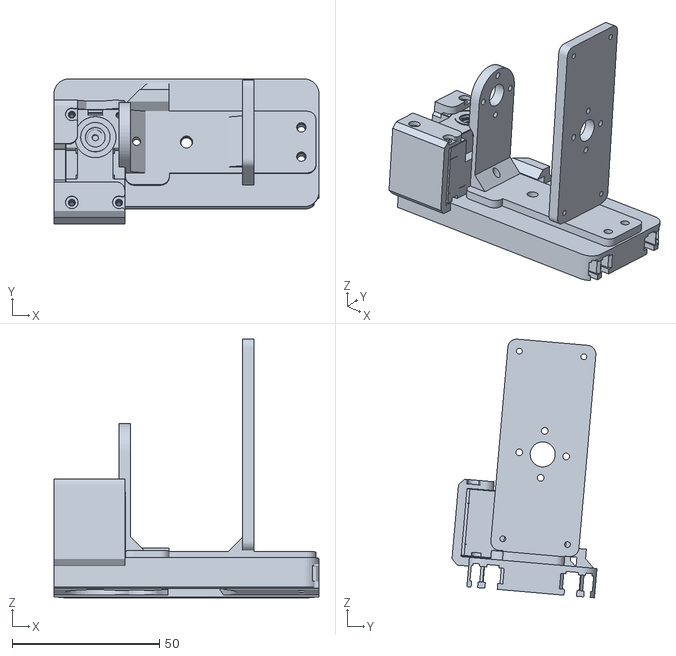
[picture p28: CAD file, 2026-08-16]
train_arm/humanoid_urdf_description/meshes/rgripper_1.stl
90.0 x 49.2 x 87.9

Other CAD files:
legs_description/meshes/rl4_1.stl
legs_description/meshes/ll6_1.stl
3d/ll5.stl
legs_description/meshes/rl5_1.stl
3d/ll1.stl
3d/ll2.stl
3d/ll3.stl
3d/rl2.stl
3d/rl3.stl
3d/rl4.stl
3d/rl6.stl
legs_description/meshes/base_link.stl
legs_description/meshes/ll1_1.stl
legs_description/meshes/ll2_1.stl
legs_description/meshes/ll3_1.stl
legs_description/meshes/ll5_1.stl
legs_description/meshes/rl2_1.stl
legs_description/meshes/rl3_1.stl
train_arm/humanoid_urdf_description/meshes/lelbow_1.stl
train_arm/humanoid_urdf_description/meshes/lgrip_fin1_1.stl
train_arm/humanoid_urdf_description/meshes/lgrip_fin2_1.stl
train_arm/humanoid_urdf_description/meshes/lgrip_gear_1.stl
train_arm/humanoid_urdf_description/meshes/lgripper_1.stl
train_arm/humanoid_urdf_description/meshes/ll3_1.stl
train_arm/humanoid_urdf_description/meshes/ll4_1.stl
train_arm/humanoid_urdf_description/meshes/ll6_1.stl
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

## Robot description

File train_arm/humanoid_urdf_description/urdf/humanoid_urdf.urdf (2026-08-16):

<?xml version="1.0" ?>
<robot name="humanoid_urdf" xmlns:xacro="http://www.ros.org/wiki/xacro">

<xacro:include filename="$(find humanoid_urdf_description)/urdf/materials.xacro" />
<xacro:include filename="$(find humanoid_urdf_description)/urdf/humanoid_urdf.trans" />
<xacro:include filename="$(find humanoid_urdf_description)/urdf/humanoid_urdf.gazebo" />
<link name="base_link">
  <inertial>
    <origin xyz="-0.005799007929849412 -0.0019422579747158052 0.3350890323845471" rpy="0 0 0"/>
    <mass value="0.6659240922979891"/>
    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
  </inertial>
  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
</link>

<link name="lgrip_gear_1">
  <inertial>
    <origin xyz="-2.2601354418907982e-07 0.00021978337031332285 -0.002507423969669409" rpy="0 0 0"/>
    <mass value="0.002515348048999408"/>
    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
  </inertial>
  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
</link>

<link name="lgrip_fin2_1">
  <inertial>
    <origin xyz="0.015181617337629228 0.022421417269875246 -0.036871927918564223" rpy="0 0 0"/>
    <mass value="0.03333747674318192"/>
    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
  </inertial>
  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
</link>

<link name="lgrip_fin1_1">
  <inertial>
    <origin xyz="-0.015181918559323089 -0.01567873890590002 -0.04020446832798316" rpy="0 0 0"/>
    <mass value="0.03333747674318192"/>
    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
  </inertial>
  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
</link>

<link name="lshd_2xl_1">
  <inertial>
    <origin xyz="0.01821386883633947 0.01229677057931565 -0.003677196420889317" rpy="0 0 0"/>
    <mass value="0.08476710413561503"/>
    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
  </inertial>
  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
</link>

<link name="lwrist_1">
  <inertial>
    <origin xyz="-0.0007578337003173279 -0.027030919070178794 0.009098655338731915" rpy="0 0 0"/>
    <mass value="0.08793324627970979"/>
    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
  </inertial>
  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
</link>

<link name="lgripper_1">
  <inertial>
    <origin xyz="0.010330923951847456 0.005332475134864734 -0.026876175254260504" rpy="0 0 0"/>
    <mass value="0.07577726651931928"/>
    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
  </inertial>
  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
</link>

<link name="rwrist_1">
  <inertial>
    <origin xyz="0.0007573816822589452 0.027031509052206026 0.009098655484584856" rpy="0 0 0"/>
    <mass value="0.08793324627970973"/>
    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
  </inertial>
  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
</link>

<link name="rgripper_1">
  <inertial>
    <origin xyz="-0.02767578642610572 -0.005392712548755937 -0.026870853391020216" rpy="0 0 0"/>
    <mass value="0.07577726656267422"/>
    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
  </inertial>
  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
</link>

<link name="rgrip_gear_1">
  <inertial>
    <origin xyz="-2.2601350544229626e-07 -0.00021919310032275652 -0.0025074238490095935" rpy="0 0 0"/>
    <mass value="0.002515348048999408"/>
    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
  </inertial>
  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
</link>

<link name="rgrip_fin1_1">
  <inertial>
    <origin xyz="-0.015182069364682959 -0.022421826999883168 -0.036871927797902965" rpy="0 0 0"/>
    <mass value="0.03333747674318192"/>
    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
  </inertial>
  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
</link>

<link name="rgrip_fin2_1">
  <inertial>
    <origin xyz="0.015181768143095464 0.015678329175891376 -0.040204468207325345" rpy="0 0 0"/>
    <mass value="0.03333747674318192"/>
    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
  </inertial>
  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
</link>

<link name="rshd_pitch_1">
  <inertial>
    <origin xyz="-2.2601349694909012e-07 -0.012912922526919862 -1.5564210659180233e-07" rpy="0 0 0"/>
    <mass value="0.0157117409033363"/>
    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
  </inertial>
  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
</link>

<link name="lshd_pitch_1">
  <inertial>
    <origin xyz="-2.2601352955842202e-07 0.01291351242690654 -1.5564210747998075e-07" rpy="0 0 0"/>
    <mass value="0.0157117409033363"/>
    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
  </inertial>
  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
</link>

<link name="neck_1">
  <inertial>
    <origin xyz="-5.8993040728053114e-06 0.0005056988631585504 0.00783028892749299" rpy="0 0 0"/>
    <mass value="0.005062828410877468"/>
    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
  </inertial>
  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
</link>

<link name="head_1">
  <inertial>
    <origin xyz="0.00334478594326635 0.014060597301845282 0.01845971527487761" rpy="0 0 0"/>
    <mass value="0.031003182579640465"/>
    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
  </inertial>
  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
</link>

<link name="ll1_1">
  <inertial>
    <origin xyz="-0.000324868161245464 2.5123219721256973e-07 -0.01537395502683428" rpy="0 0 0"/>
    <mass value="0.012917415150155305"/>
    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
  </inertial>
  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
</link>

<link name="ll2_1">
  <inertial>
    <origin xyz="-0.04091824568283125 0.00024752093223290306 -0.01215740264201931" rpy="0 0 0"/>
    <mass value="0.13078226931984757"/>
    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
  </inertial>
  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
</link>

<link name="rl1_1">
  <inertial>
    <origin xyz="-0.00032486816124601466 2.512321968101139e-07 -0.01537395502237704" rpy="0 0 0"/>
    <mass value="0.01291741515015535"/>
    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
  </inertial>
  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
</link>

<link name="rl4_1">
  <inertial>
    <origin xyz="-1.5621050886583526e-07 -0.020217643412060678 -0.046243227760864175" rpy="0 0 0"/>
    <mass value="0.022805605859881364"/>
    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
  </inertial>
  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
</link>

<link name="rl6_1">
  <inertial>
    <origin xyz="0.027462674832497574 -0.011389521836556699 -0.030839874026291004" rpy="0 0 0"/>
    <mass value="0.08571227124117571"/>
    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
  </inertial>
  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
</link>

<link name="ll4_1">
  <inertial>
    <origin xyz="-1.562105035831686e-07 0.020218097688314243 -0.046243243451467256" rpy="0 0 0"/>
    <mass value="0.02280560585988143"/>
    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
  </inertial>
  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
</link>

<link name="ll6_1">
  <inertial>
    <origin xyz="0.027462674832506355 0.011389976112803235 -0.030839874026292367" rpy="0 0 0"/>
    <mass value="0.08571227124117566"/>
    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
  </inertial>
  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
</link>

<link name="rl2_1">
  <inertial>
    <origin xyz="-0.0409182456828239 -0.00024523842877196417 -0.012157402642023613" rpy="0 0 0"/>
    <mass value="0.13078226931984804"/>
    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
  </inertial>
  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
</link>

<link name="rl3_1">
  <inertial>
    <origin xyz="-1.798758521272606e-07 -0.019595944137411357 -0.06959639641496687" rpy="0 0 0"/>
    <mass value="0.07734223549835353"/>
    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
  </inertial>
  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
</link>

<link name="lshd_yaw_1">
  <inertial>
    <origin xyz="-2.303931278258009e-07 0.0017691391517789395 -0.02021746469897523" rpy="0 0 0"/>
    <mass value="0.016893673089971303"/>
    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
  </inertial>
  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
</link>

<link name="lelbow_1">
  <inertial>
    <origin xyz="-2.2597876358013136e-07 0.02138112207525253 -0.026843371313703568" rpy="0 0 0"/>
    <mass value="0.08838540484513303"/>
    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
  </inertial>
  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
</link>

<link name="rshd_yaw_1">
  <inertial>
    <origin xyz="-2.2179481884432306e-07 -0.0017685513347718562 -0.02021746326152224" rpy="0 0 0"/>
    <mass value="0.01689367308997018"/>
    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
  </inertial>
  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
</link>

<link name="relbow_1">
  <inertial>
    <origin xyz="-2.260482717952872e-07 -0.021380531805275896 -0.02684337119303143" rpy="0 0 0"/>
    <mass value="0.08838540484513334"/>
    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
  </inertial>
  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
</link>

<link name="ll5_1">
  <inertial>
    <origin xyz="-0.022668245682816324 0.019245692705025214 0.01214920393557916" rpy="0 0 0"/>
    <mass value="0.13078226931984807"/>
    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
  </inertial>
  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
</link>

<link name="rl5_1">
  <inertial>
    <origin xyz="-0.022668245682832017 -0.019247066655979854 0.012149203935575538" rpy="0 0 0"/>
    <mass value="0.13078226931984768"/>
    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
  </inertial>
  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
</link>

<link name="rshd_2xl_1">
  <inertial>
    <origin xyz="0.01850518462853406 -0.012677886438757169 -0.003895381622762928" rpy="0 0 0"/>
    <mass value="0.08457536214369274"/>
    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
  </inertial>
  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
</link>

<link name="ll3_1">
  <inertial>
    <origin xyz="-1.798738220449951e-07 -0.016003601262554387 -0.06959639641553317" rpy="0 0 0"/>
    <mass value="0.07734223550377772"/>
    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
  </inertial>
  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
</link>

<joint name="lgripper_joint" type="revolute">
  <origin xyz="0.019 0.00346 -0.039549" rpy="0 0 0"/>
  <parent link="lgripper_1"/>
  <child link="lgrip_gear_1"/>
  <axis xyz="-0.0 0.087156 -0.996195"/>
  <limit upper="0.261799" lower="-1.745329" effort="100" velocity="100"/>
</joint>

<joint name="lgrip_fin2_slider" type="prismatic">
  <origin xyz="0.019 -0.015736 -0.040425" rpy="0 0 0"/>
  <parent link="lgripper_1"/>
  <child link="lgrip_fin2_1"/>
  <axis xyz="1.0 0.0 -0.0"/>
  <limit upper="0.0" lower="0.0" effort="100" velocity="100"/>
</joint>
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

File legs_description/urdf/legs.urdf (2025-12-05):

<?xml version="1.0" ?>
<robot name="legs" xmlns:xacro="http://www.ros.org/wiki/xacro">

<xacro:include filename="$(find legs_description)/urdf/materials.xacro" />
<xacro:include filename="$(find legs_description)/urdf/legs.trans" />
<xacro:include filename="$(find legs_description)/urdf/legs.gazebo" />
<link name="base_link">
  <inertial>
    <origin xyz="-0.01038463935776527 -0.001959748613991949 0.27679462082056655" rpy="0 0 0"/>
    <mass value="1.6231499555523392"/>
    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
  </inertial>
  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
</link>

<link name="ll1_1">
  <inertial>
    <origin xyz="0.0003258530392218951 2.0304405719956398e-07 -0.015373955026833724" rpy="0 0 0"/>
    <mass value="0.07740588467841157"/>
    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
  </inertial>
  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
</link>

<link name="rl1_1">
  <inertial>
    <origin xyz="0.00032585303922116676 2.03044057393853e-07 -0.0153739550223774" rpy="0 0 0"/>
    <mass value="0.07740588467841183"/>
    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
  </inertial>
  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
</link>

<link name="ll2_1">
  <inertial>
    <origin xyz="0.0409182305608098 -0.00024706665597870603 -0.012157402642017201" rpy="0 0 0"/>
    <mass value="0.783695277985346"/>
    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
  </inertial>
  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
</link>

<link name="rl2_1">
  <inertial>
    <origin xyz="0.040918230560799 0.00024569270502586976 -0.012157402642024251" rpy="0 0 0"/>
    <mass value="0.7836952779853489"/>
    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
  </inertial>
  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
</link>

<link name="ll3_1">
  <inertial>
    <origin xyz="1.6475180468077284e-07 0.020604055538808168 -0.06959639641553253" rpy="0 0 0"/>
    <mass value="0.4634630142783627"/>
    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
  </inertial>
  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
</link>

<link name="rl3_1">
  <inertial>
    <origin xyz="1.64753828116879e-07 -0.020603601586335014 -0.06959639641496773" rpy="0 0 0"/>
    <mass value="0.46346301424585895"/>
    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
  </inertial>
  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
</link>

<link name="ll4_1">
  <inertial>
    <origin xyz="1.4108849107291946e-07 0.019982356528334064 -0.046243243451466604" rpy="0 0 0"/>
    <mass value="0.1366595465649383"/>
    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
  </inertial>
  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
</link>

<link name="rl4_1">
  <inertial>
    <origin xyz="1.4108848453908349e-07 -0.019981902311686436 -0.046243227760865105" rpy="0 0 0"/>
    <mass value="0.13665954656493792"/>
    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
  </inertial>
  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
</link>

<link name="ll5_1">
  <inertial>
    <origin xyz="0.022668230560806926 0.020654761511622863 0.01214920393558138" rpy="0 0 0"/>
    <mass value="0.7836952779853491"/>
    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
  </inertial>
  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
</link>

<link name="rl5_1">
  <inertial>
    <origin xyz="0.022668230560807787 -0.0206524791273723 0.01214920393557465" rpy="0 0 0"/>
    <mass value="0.7836952779853467"/>
    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
  </inertial>
  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
</link>

<link name="ll6_1">
  <inertial>
    <origin xyz="0.022026213497528885 -0.011389521896155538 -0.030839601164419382" rpy="0 0 0"/>
    <mass value="0.5136193353001747"/>
    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
  </inertial>
  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
</link>

<link name="rl6_1">
  <inertial>
    <origin xyz="0.02202621349751909 0.011389976053204014 -0.030839601164419903" rpy="0 0 0"/>
    <mass value="0.513619335300175"/>
    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
  </inertial>
  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
</link>

<joint name="lbase_joint" type="revolute">
  <origin xyz="0.001007 -0.06197 0.258033" rpy="0 0 0"/>
  <parent link="base_link"/>
  <child link="ll1_1"/>
  <axis xyz="0.0 -0.0 -1.0"/>
  <limit upper="0.0" lower="-1.570796" effort="100" velocity="100"/>
</joint>

<joint name="rbase_joint" type="revolute">
  <origin xyz="0.001007 0.05803 0.258033" rpy="0 0 0"/>
  <parent link="base_link"/>
  <child link="rl1_1"/>
  <axis xyz="0.0 -0.0 -1.0"/>
  <limit upper="1.570796" lower="0.0" effort="100" velocity="100"/>
</joint>

<joint name="ll1_joint" type="revolute">
  <origin xyz="-0.020419 0.0 -0.0345" rpy="0 0 0"/>
  <parent link="ll1_1"/>
  <child link="ll2_1"/>
  <axis xyz="1.0 0.0 0.0"/>
  <limit upper="0.436332" lower="-1.570796" effort="100" velocity="100"/>
</joint>

<joint name="rl1_joint" type="revolute">
  <origin xyz="-0.020419 0.0 -0.0345" rpy="0 0 0"/>
  <parent link="rl1_1"/>
  <child link="rl2_1"/>
  <axis xyz="1.0 0.0 0.0"/>
  <limit upper="1.570796" lower="-0.436332" effort="100" velocity="100"/>
</joint>

<joint name="ll2_joint" type="revolute">
  <origin xyz="0.01825 -0.0209 -8e-06" rpy="0 0 0"/>
  <parent link="ll2_1"/>
  <child link="ll3_1"/>
  <axis xyz="-0.0 1.0 -0.0"/>
  <limit upper="1.570796" lower="-0.436332" effort="100" velocity="100"/>
</joint>
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

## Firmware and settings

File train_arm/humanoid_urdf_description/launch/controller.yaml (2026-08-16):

humanoid_urdf_controller:
  # Publish all joint states -----------------------------------
  joint_state_controller:
    type: joint_state_controller/JointStateController
    publish_rate: 50

  # Position Controllers --------------------------------------
  lgripper_joint_position_controller:
    type: effort_controllers/JointPositionController
    joint: lgripper_joint
    pid: {p: 100.0, i: 0.01, d: 10.0}
  lgrip_fin2_slider_position_controller:
    type: effort_controllers/JointPositionController
    joint: lgrip_fin2_slider
    pid: {p: 100.0, i: 0.01, d: 10.0}
  lgrip_fin1_slider_position_controller:
    type: effort_controllers/JointPositionController
    joint: lgrip_fin1_slider
    pid: {p: 100.0, i: 0.01, d: 10.0}
  lshd_yaw_joint_position_controller:
    type: effort_controllers/JointPositionController
    joint: lshd_yaw_joint
    pid: {p: 100.0, i: 0.01, d: 10.0}
  lwrist_pitch_joint_position_controller:
    type: effort_controllers/JointPositionController
    joint: lwrist_pitch_joint
    pid: {p: 100.0, i: 0.01, d: 10.0}
  lwrist_yaw_joint_position_controller:
    type: effort_controllers/JointPositionController
    joint: lwrist_yaw_joint
    pid: {p: 100.0, i: 0.01, d: 10.0}
  rwrist_pitch_joint_position_controller:
    type: effort_controllers/JointPositionController
    joint: rwrist_pitch_joint
    pid: {p: 100.0, i: 0.01, d: 10.0}
  rwrist_yaw_joint_position_controller:
    type: effort_controllers/JointPositionController
    joint: rwrist_yaw_joint
    pid: {p: 100.0, i: 0.01, d: 10.0}
  rgripper_joint_position_controller:
    type: effort_controllers/JointPositionController
    joint: rgripper_joint
    pid: {p: 100.0, i: 0.01, d: 10.0}
  rgrip_fin1_slider_position_controller:
    type: effort_controllers/JointPositionController
    joint: rgrip_fin1_slider
    pid: {p: 100.0, i: 0.01, d: 10.0}
  rgrip_fin2_slider_position_controller:
    type: effort_controllers/JointPositionController
    joint: rgrip_fin2_slider
    pid: {p: 100.0, i: 0.01, d: 10.0}
  rshd_pitch_joint_position_controller:
    type: effort_controllers/JointPositionController
    joint: rshd_pitch_joint
    pid: {p: 100.0, i: 0.01, d: 10.0}
  lshd_pitch_joint_position_controller:
    type: effort_controllers/JointPositionController
    joint: lshd_pitch_joint
    pid: {p: 100.0, i: 0.01, d: 10.0}
  neck_roll_joint_position_controller:
    type: effort_controllers/JointPositionController
    joint: neck_roll_joint
    pid: {p: 100.0, i: 0.01, d: 10.0}
  neck_pitch_joint_position_controller:
    type: effort_controllers/JointPositionController
    joint: neck_pitch_joint
    pid: {p: 100.0, i: 0.01, d: 10.0}
  lbase_joint_position_controller:
    type: effort_controllers/JointPositionController
    joint: lbase_joint
    pid: {p: 100.0, i: 0.01, d: 10.0}
  ll1_joint_position_controller:
    type: effort_controllers/JointPositionController
    joint: ll1_joint
    pid: {p: 100.0, i: 0.01, d: 10.0}
  rbase_joint_position_controller:
    type: effort_controllers/JointPositionController
    joint: rbase_joint
    pid: {p: 100.0, i: 0.01, d: 10.0}
  rl3_joint_position_controller:
    type: effort_controllers/JointPositionController
    joint: rl3_joint
    pid: {p: 100.0, i: 0.01, d: 10.0}
  rl5_joint_position_controller:
    type: effort_controllers/JointPositionController
    joint: rl5_joint
    pid: {p: 100.0, i: 0.01, d: 10.0}
  ll3_joint_position_controller:
    type: effort_controllers/JointPositionController
    joint: ll3_joint
    pid: {p: 100.0, i: 0.01, d: 10.0}
  ll5_joint_position_controller:
    type: effort_controllers/JointPositionController
    joint: ll5_joint
    pid: {p: 100.0, i: 0.01, d: 10.0}
  rl1_joint_position_controller:
    type: effort_controllers/JointPositionController
    joint: rl1_joint
    pid: {p: 100.0, i: 0.01, d: 10.0}
  rl2_joint_position_controller:
    type: effort_controllers/JointPositionController
    joint: rl2_joint
    pid: {p: 100.0, i: 0.01, d: 10.0}
  lshd_roll_joint_position_controller:
    type: effort_controllers/JointPositionController
    joint: lshd_roll_joint
    pid: {p: 100.0, i: 0.01, d: 10.0}
  lelbow_joint_position_controller:
    type: effort_controllers/JointPositionController
    joint: lelbow_joint
    pid: {p: 100.0, i: 0.01, d: 10.0}
  rshd_roll_joint_position_controller:
    type: effort_controllers/JointPositionController
    joint: rshd_roll_joint
    pid: {p: 100.0, i: 0.01, d: 10.0}
  relbow_joint_position_controller:
    type: effort_controllers/JointPositionController
    joint: relbow_joint
    pid: {p: 100.0, i: 0.01, d: 10.0}
  ll4_joint_position_controller:
    type: effort_controllers/JointPositionController
    joint: ll4_joint
    pid: {p: 100.0, i: 0.01, d: 10.0}
  rl4_joint_position_controller:
    type: effort_controllers/JointPositionController
    joint: rl4_joint
    pid: {p: 100.0, i: 0.01, d: 10.0}
  rshd_yaw_joint_position_controller:
    type: effort_controllers/JointPositionController
    joint: rshd_yaw_joint
    pid: {p: 100.0, i: 0.01, d: 10.0}
  ll2_joint_position_controller:
    type: effort_controllers/JointPositionController
    joint: ll2_joint
    pid: {p: 100.0, i: 0.01, d: 10.0}

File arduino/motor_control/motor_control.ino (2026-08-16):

#include <Dynamixel2Arduino.h>
#include <IMU.h>

#define DXL_SERIAL   Serial3
#define DEBUG_SERIAL Serial
#define RPI_SERIAL   Serial   // 라즈베리파이 USB 시리얼 연결 (OpenCR은 Serial이 USB 가상 시리얼입니다)

cIMU imu;
const int DXL_DIR_PIN = 84;
Dynamixel2Arduino dxl(DXL_SERIAL, DXL_DIR_PIN);

using namespace ControlTableItem;

const float DXL_PROTOCOL_VERSION = 2.0;
const uint32_t BAUDRATE = 57600;

const uint8_t IDS[28] = {
  1, 2, 3, 4, 5, 6,    // 왼발 (1~6)
  7, 8, 9, 10, 11, 12,  // 오른발 (7~12)
  13,14,
  15,16,17,18,19,20,21,
  22,23,24,25,26,27,28
};

int32_t DYNAMIC_CENTER_POS[28] = {0, };


const float URDF_MIN_RAD[28] = {
  -1.57,   -1.57,   -1.57,    0.0,   -0.43, -1.04, // 왼발 (1번: -1.57)
  0.0,     -0.43,   -0.43,   -1.39,  -1.57, -1.57,  // 오른발 (7번: 0.0)
  -1.570796,-1.570796,
  -3.141592,0.0,-1.570796,
  -2.094395,-1.570796,-0.349066,-5.2360,
  -3.141592,0.0,-1.570796,
  -2.094395,-1.570796,-0.349066,-5.2360

};

const float URDF_MAX_RAD[28] = {
  0.0,    0.43,     0.43,     1.39,   1.57,  1.57,  // 왼발 (1번: 0.0)
  1.57,   1.57,     1.57,     0.0,    0.43,  1.04,   // 오른발 (7번: 1.57)
  1.570796,1.570796,
  3.141592,1.570796,1.570796,
  2.094395,1.570796,0.349066,0.8727,
  3.141592,1.570796,1.570796,
  2.094395,1.570796,0.349066,0.8727

};





const float RAD_TO_DXL_STEP = 651.74;

// void setup()
// {
//   DEBUG_SERIAL.begin(115200);
//   while(!DEBUG_SERIAL);

//   DEBUG_SERIAL.println("==============================================");
//   DEBUG_SERIAL.println("===  PERFECT DIRECTION SYMMETRIC CONTROLLER ===");
//   DEBUG_SERIAL.println("==============================================");

//   dxl.begin(BAUDRATE);
//   dxl.setPortProtocolVersion(DXL_PROTOCOL_VERSION);

//   DEBUG_SERIAL.println(">> Capturing current positions...");
//   for(int i = 0; i < 12; i++)
//   {
//     uint8_t id = IDS[i];
//     if(dxl.ping(id)) {
//       DYNAMIC_CENTER_POS[i] = dxl.getPresentPosition(id, UNIT_RAW);
//       DEBUG_SERIAL.print(" Motor ID ["); DEBUG_SERIAL.print(id);
//       DEBUG_SERIAL.print("] Center (0 rad) -> Raw: "); DEBUG_SERIAL.println(DYNAMIC_CENTER_POS[i]);
//     } else {
//       DEBUG_SERIAL.print("⚠️ Ping FAILED for ID: "); DEBUG_SERIAL.println(id);
//       DYNAMIC_CENTER_POS[i] = 2048; 
//     }
//   }

//   DEBUG_SERIAL.println("\n>> Enabling Extended Position Mode...");
//   for(int i = 0; i < 12; i++)
//   {
//     uint8_t id = IDS[i];
//     dxl.torqueOff(id);
//     dxl.setOperatingMode(id, OP_EXTENDED_POSITION); 

//     dxl.writeControlTableItem(PROFILE_VELOCITY, id, 30);
//     dxl.writeControlTableItem(PROFILE_ACCELERATION, id, 10);
//     dxl.writeControlTableItem(POSITION_P_GAIN, id, 850); 
//     dxl.writeControlTableItem(POSITION_D_GAIN, id, 0); 

//     dxl.torqueOn(id);
//     dxl.setGoalPosition(id, (uint32_t)DYNAMIC_CENTER_POS[i], UNIT_RAW);
//     delay(20);
//   }
//   DEBUG_SERIAL.println(">> System Ready.");
// }

void setup()
{
  DEBUG_SERIAL.begin(115200); // 파이썬 통신 속도와 일치시킵니다.
  
  dxl.begin(BAUDRATE);
  dxl.setPortProtocolVersion(DXL_PROTOCOL_VERSION);

  for(int i = 0; i < 28; i++) {
    uint8_t id = IDS[i];
    if(dxl.ping(id)) {
      DYNAMIC_CENTER_POS[i] = dxl.getPresentPosition(id, UNIT_RAW);
    } else {
      DYNAMIC_CENTER_POS[i] = 2048; 
    }
  }

  for(int i = 0; i < 28; i++) {
    uint8_t id = IDS[i];
    dxl.torqueOff(id);
    dxl.setOperatingMode(id, OP_EXTENDED_POSITION); 
    dxl.writeControlTableItem(PROFILE_VELOCITY, id, 30);
    dxl.writeControlTableItem(PROFILE_ACCELERATION, id, 10);
    dxl.writeControlTableItem(POSITION_P_GAIN, id, 850); 
    dxl.writeControlTableItem(POSITION_D_GAIN, id, 0); 
    dxl.torqueOn(id);
    dxl.setGoalPosition(id, (uint32_t)DYNAMIC_CENTER_POS[i], UNIT_RAW);
    delay(20);
  }
  imu.begin();
  delay(100);
}

// void loop()
// {
//   if (DEBUG_SERIAL.available() > 0)
//   {
//     String inputString = DEBUG_SERIAL.readStringUntil('\n');
//     inputString.trim();

//     if (inputString.length() == 0) return;

//     if (inputString == "0") {
//       DEBUG_SERIAL.println("\n🚨 [RESET] Returning ALL to Center.");
//       for(int i = 0; i < 12; i++) {
//         dxl.setGoalPosition(IDS[i], (uint32_t)DYNAMIC_CENTER_POS[i], UNIT_RAW);
//       }
//       return;
//     }

//     DEBUG_SERIAL.println("\n--- Processing Symmetrical Command ---");

//     int currentPos = 0;
//     int nextSlash = 0;

//     while (currentPos < inputString.length()) {
//       nextSlash = inputString.indexOf('/', currentPos);
      
//       String token;
//       if (nextSlash == -1) {
//         token = inputString.substring(currentPos);
//         currentPos = inputString.length();
//       } else {
//         token = inputString.substring(currentPos, nextSlash);
//         currentPos = nextSlash + 1;
//       }

//       token.trim();
//       if (token.length() == 0) continue;

//       int commaIndex = token.indexOf(',');
//       if (commaIndex == -1) {
//         DEBUG_SERIAL.print("⚠️ Skip Invalid Token: "); DEBUG_SERIAL.println(token);
//         continue;
//       }

//       String idPart = token.substring(0, commaIndex);
//       String offsetPart = token.substring(commaIndex + 1);

//       int targetID = idPart.toInt();
//       int32_t offsetInput = offsetPart.toInt();

//       if (targetID < 1 || targetID > 12) {
//         DEBUG_SERIAL.print("⚠️ Skip Invalid ID: "); DEBUG_SERIAL.println(targetID);
//         continue;
//       }

//       int idx = targetID - 1;
//       int32_t center = DYNAMIC_CENTER_POS[idx];

//       // 1. 기본 URDF 라디안 기반 제한값 계산
//       int32_t min_offset_limit = (int32_t)(URDF_MIN_RAD[idx] * RAD_TO_DXL_STEP);
//       int32_t max_offset_limit = (int32_t)(URDF_MAX_RAD[idx] * RAD_TO_DXL_STEP);


//       // if (targetID == 11|| targetID == 12) {
//       //   offsetInput = -offsetInput; // 입력 부호 반전 (원하는 방향 전환)
        
//       //   // ★ 9번은 이미 배열이 양수(0.0 ~ 1.57)로 완벽하므로 가드 장벽을 반전시키지 않고 그대로 유지합니다!
//       //   DEBUG_SERIAL.print(" [INFO] ID 9 Direction Inverted -> Offset: ");
//       //   DEBUG_SERIAL.println(offsetInput);
//       // }

//       // 3. URDF 오프셋 범위 내로 가드 클램핑 (이제 9번은 0 ~ 1023 가드를 정상 적용받습니다)
//       if (offsetInput < min_offset_limit) {
//         DEBUG_SERIAL.print(" [URDF LIMIT] ID "); DEBUG_SERIAL.print(targetID);
//         DEBUG_SERIAL.print(" Min Limit! Bound to: "); DEBUG_SERIAL.println(min_offset_limit);
//         offsetInput = min_offset_limit;
//       }
//       if (offsetInput > max_offset_limit) {
//         DEBUG_SERIAL.print(" [URDF LIMIT] ID "); DEBUG_SERIAL.print(targetID);
//         DEBUG_SERIAL.print(" Max Limit! Bound to: "); DEBUG_SERIAL.println(max_offset_limit);
//         offsetInput = max_offset_limit;
//       }

//       // 4. 최종 타겟 계산 및 Extended Position 모드에 맞게 전송
//       int32_t finalTarget = center + offsetInput;

//       DEBUG_SERIAL.print(" ▶ [EXECUTE] ID: "); DEBUG_SERIAL.print(targetID);
//       DEBUG_SERIAL.print(" -> Offset: "); DEBUG_SERIAL.print(offsetInput);
//       DEBUG_SERIAL.print(" -> Goal Raw: "); DEBUG_SERIAL.println(finalTarget);

//       // Extended Mode에서는 부호 있는 32비트 값(finalTarget)을 그대로 던져주면 모터가 알아서 경계선을 넘나듭니다.
//       dxl.setGoalPosition(targetID, finalTarget, UNIT_RAW);
//     }
//     DEBUG_SERIAL.println("--------------------------------");
//   }
// }



void loop()
{
  // 라즈베리파이(RPI_SERIAL)로부터 데이터 수신
  if (RPI_SERIAL.available() > 0)
  {
    String inputString = RPI_SERIAL.readStringUntil('\n');
    inputString.trim();

    if (inputString.length() == 0) return;

    if (inputString == "0") {
      for(int i = 0; i < 28; i++) {
        dxl.setGoalPosition(IDS[i], (uint32_t)DYNAMIC_CENTER_POS[i], UNIT_RAW);
      }
      RPI_SERIAL.println("ACK:RESET");
      return;
    }

    int currentPos = 0;
    int nextSlash = 0;

    while (currentPos < inputString.length()) {
      nextSlash = inputString.indexOf('/', currentPos);
      
      String token;
      if (nextSlash == -1) {
        token = inputString.substring(currentPos);
        currentPos = inputString.length();
      } else {
        token = inputString.substring(currentPos, nextSlash);
        currentPos = nextSlash + 1;
      }

      token.trim();
      if (token.length() == 0) continue;

      int commaIndex = token.indexOf(',');
      if (commaIndex == -1) continue;

      String idPart = token.substring(0, commaIndex);
      String offsetPart = token.substring(commaIndex + 1);

      int targetID = idPart.toInt();
      int32_t offsetInput = offsetPart.toInt();

      if (targetID < 1 || targetID > 28) continue;

      int idx = targetID - 1;
      int32_t center = DYNAMIC_CENTER_POS[idx];

      int32_t min_offset_limit = (int32_t)(URDF_MIN_RAD[idx] * RAD_TO_DXL_STEP);
      int32_t max_offset_limit = (int32_t)(URDF_MAX_RAD[idx] * RAD_TO_DXL_STEP);

      // 물리적 방향/한계 분기문
      if (targetID == 3|| targetID == 4|| targetID == 5|| targetID == 6||targetID == 9|| targetID == 10|| targetID == 11|| targetID == 12) {
        offsetInput = -offsetInput; 
      }


      // 가드 클램핑
      if (offsetInput < min_offset_limit) offsetInput = min_offset_limit;
      if (offsetInput > max_offset_limit) offsetInput = max_offset_limit;

      int32_t finalTarget = center + offsetInput;
      dxl.setGoalPosition(targetID, finalTarget, UNIT_RAW);
    }
    // 라즈베리파이에게 명령을 잘 처리했다고 응답 전송 (파이썬 블로킹 방지용)
    RPI_SERIAL.println("ACK:OK");
  }

  imu.update();
  // 2. IMU 데이터 읽기 및 라즈베리파이로 송출 (추가할 부분)
  // 50Hz~100Hz 주기로 보낼 수 있도록 타이머 처리
  // float roll  = imu.rpy[0];  // Index 0 : Roll
  // float pitch = imu.rpy[1];  // Index 1 : Pitch
  // float yaw   = imu.rpy[2];  // Index 2 : Yaw
  // // "IMU:롤값,피치값,요값" 형태로 한 줄씩 출력 (\n)
  // Serial.print("IMU:");
  // Serial.print(roll); Serial.print(",");
  // Serial.print(pitch); Serial.print(",");
  // Serial.println(yaw);

  float raw_roll  = imu.rpy[0];
  float raw_pitch = imu.rpy[1];
  float raw_yaw   = imu.rpy[2];

  // 시계방향 90도 회전 보정
  float corrected_roll  = -raw_roll;
  float corrected_pitch = -raw_pitch;
  float corrected_yaw   =  raw_yaw;

  // yaw 범위 정규화 (-180 ~ 180)
  if (corrected_yaw < -180.0f) corrected_yaw += 360.0f;
  if (corrected_yaw >  180.0f) corrected_yaw -= 360.0f;

  Serial.print("IMU:");
  Serial.print(corrected_roll);  Serial.print(",");
  Serial.print(corrected_pitch); Serial.print(",");
  Serial.println(corrected_yaw);

  delay(10);
  
}

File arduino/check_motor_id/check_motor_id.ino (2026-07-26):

#include <Dynamixel2Arduino.h>

#define DXL_SERIAL   Serial3
#define DEBUG_SERIAL Serial

const int DXL_DIR_PIN = 84;

Dynamixel2Arduino dxl(DXL_SERIAL, DXL_DIR_PIN);

void testBaud(uint32_t baud)
{
  dxl.begin(baud);

  DEBUG_SERIAL.println();
  DEBUG_SERIAL.print("Testing baud: ");
  DEBUG_SERIAL.println(baud);

  bool found = false;

  for(int id = 0; id < 30; id++)
  {
    if(dxl.ping(id))
    {
      DEBUG_SERIAL.print("Found ID: ");
      DEBUG_SERIAL.println(id);

      found = true;
    }
  }

  if(!found)
  {
    DEBUG_SERIAL.println("No motor found");
  }
}

void setup()
{
  DEBUG_SERIAL.begin(115200);

  while(!DEBUG_SERIAL);

  dxl.setPortProtocolVersion(2.0);

  DEBUG_SERIAL.println("=== Dynamixel Scan Start ===");

  testBaud(57600);
  // testBaud(115200);
  // testBaud(1000000);
  // testBaud(2000000);

  DEBUG_SERIAL.println("=== Scan End ===");
}

void loop()
{
}

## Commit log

2026-07-26 edit rl
    [humanoid.urdf]
2026-08-15 edit urdf
2026-08-16 add pt
    [controller.yaml, humanoid.urdf, humanoid_urdf.urdf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]
